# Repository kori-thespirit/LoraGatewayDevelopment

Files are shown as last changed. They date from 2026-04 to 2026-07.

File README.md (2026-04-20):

# ESP32-S3 Pin
| Pin Number | Pin Name | Function | Device |
| :--- | :--- | :--- | :--- |
| 5 | GPIO5 (ESP_TX) | HMI_RX | HMI Dwin |
| 6 | GPIO6 (ESP_RX) | HMI_TX | HMI Dwin |
| 39 | GPIO1 | LoRA_INTERRUPT | LoRA Module |
| 31 | GPIO38 | RESET | LoRA Module |
| 32 | GPIO39 | SCK | LoRA Module |
| 33 | GPIO40 | MISO | LoRA Module |
| 34 | GPIO41 | MOSI | LoRA Module |
| 35 | GPIO42 | CS | LoRA Module |
| 18 | GPIO10 | I2C_SCL | Module RTC_DS3231 |
| 19 | GPIO11 | I2C_SDA | Module RTC_DS3231 |
| 15 | GPIO3 | SIM_PWRKEY | SIMCOM |
| 7 | GPIO7 | SIM_RESET | SIMCOM |
| 23 | GPIO21 (ESP_TX) | SIM_RX | SIMCOM |
| 24 | GPIO47 (ESP_RX) | SIM_TX | SIMCOM |
| 12 | GPIO8 | CS | W5500_ETHERNET |
| 17 | GPIO9 | INTERRUPT | W5500_ETHERNET |
| 9 | GPIO16 | MOSI | W5500_ETHERNET |
| 10 | GPIO17 | MISO | W5500_ETHERNET |
| 11 | GPIO18 | SPI_CLK | W5500_ETHERNET |
| 22 | GPIO14 | SDIO_CLK | SD CARD |
| 8 | GPIO15 | SDIO_CMD | SD CARD |
| 20 | GPIO12 | SDIO_DATA0 | SD CARD |
| 21 | GPIO13 | SDIO_DATA1 | SD CARD |
| 4 | GPIO4 | SDIO_DATA2 | SD CARD |
| 38 | GPIO2 | SDIO_DATA3 | SD CARD |
| 26 | GPIO45 | SDIO_DET | SD CARD |

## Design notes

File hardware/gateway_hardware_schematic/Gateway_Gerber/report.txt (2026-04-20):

Warning: Width correction constrained.  The width correction value must be in the range of [0.000001 mm; 0.199999 mm] for the current design rules.
Plotted to 'C:\Users\ASUS\Documents\A0_LoraNode_Gateway\LoraGatewayDevelopment\hardware\Gateway_Schematic_V3\Gateway_Gerber\Gateway_Schematic_V3-F_Cu.gbr'.
Plotted to 'C:\Users\ASUS\Documents\A0_LoraNode_Gateway\LoraGatewayDevelopment\hardware\Gateway_Schematic_V3\Gateway_Gerber\Gateway_Schematic_V3-B_Cu.gbr'.
Plotted to 'C:\Users\ASUS\Documents\A0_LoraNode_Gateway\LoraGatewayDevelopment\hardware\Gateway_Schematic_V3\Gateway_Gerber\Gateway_Schematic_V3-F_Paste.gbr'.
Plotted to 'C:\Users\ASUS\Documents\A0_LoraNode_Gateway\LoraGatewayDevelopment\hardware\Gateway_Schematic_V3\Gateway_Gerber\Gateway_Schematic_V3-B_Paste.gbr'.
Plotted to 'C:\Users\ASUS\Documents\A0_LoraNode_Gateway\LoraGatewayDevelopment\hardware\Gateway_Schematic_V3\Gateway_Gerber\Gateway_Schematic_V3-F_Silkscreen.gbr'.
Plotted to 'C:\Users\ASUS\Documents\A0_LoraNode_Gateway\LoraGatewayDevelopment\hardware\Gateway_Schematic_V3\Gateway_Gerber\Gateway_Schematic_V3-B_Silkscreen.gbr'.
Plotted to 'C:\Users\ASUS\Documents\A0_LoraNode_Gateway\LoraGatewayDevelopment\hardware\Gateway_Schematic_V3\Gateway_Gerber\Gateway_Schematic_V3-F_Mask.gbr'.
Plotted to 'C:\Users\ASUS\Documents\A0_LoraNode_Gateway\LoraGatewayDevelopment\hardware\Gateway_Schematic_V3\Gateway_Gerber\Gateway_Schematic_V3-B_Mask.gbr'.
Plotted to 'C:\Users\ASUS\Documents\A0_LoraNode_Gateway\LoraGatewayDevelopment\hardware\Gateway_Schematic_V3\Gateway_Gerber\Gateway_Schematic_V3-Edge_Cuts.gbr'.
Created Gerber job file 'C:\Users\ASUS\Documents\A0_LoraNode_Gateway\LoraGatewayDevelopment\hardware\Gateway_Schematic_V3\Gateway_Gerber\Gateway_Schematic_V3-job.gbrjob'.
Info: Done.

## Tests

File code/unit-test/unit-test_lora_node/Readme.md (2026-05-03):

# Hướng dẫn bắt đầu với Unit Test LoRa Node
Folder unit_test_lora_node được thiết kế để kiểm tra khả năng gửi dữ liệu từ ESP32 qua module LoRa SX127x.
## 1. Clone Project và Truy cập folder unit_test_lora_node

### Clone toàn bộ dự án
```raw
git clone https://github.com/kori-thespirit/LoraGatewayDevelopment.git
```
### Truy cập folder unit_test_lora_node
```raw
cd LoraGatewayDevelopment/code/unit-test/unit_test_lora_gateway
```
## 2. Nạp code 
```raw
idf.py set-target esp32
idf.py -p COM? build flash monitor
```

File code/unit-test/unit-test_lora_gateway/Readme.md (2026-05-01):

# Hướng dẫn bắt đầu với Unit Test LoRa Gateway
Folder unit_test_lora_gateway được thiết kế để kiểm tra khả năng gửi dữ liệu từ ESP32 qua module LoRa SX127x.
## 1. Clone Project và Truy cập folder unit_test_lora_gateway

### Clone toàn bộ dự án
```raw
git clone https://github.com/kori-thespirit/LoraGatewayDevelopment.git
```
### Truy cập folder unit_test_lora_gateway
```raw
cd LoraGatewayDevelopment/code/unit-test/unit_test_lora_gateway
```
## 2. Nạp code 
```raw
idf.py set-target esp32s3
idf.py -p COM? build flash monitor
```

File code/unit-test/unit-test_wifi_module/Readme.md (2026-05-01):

# Unit Test: ESP32 Wi-Fi Station
## 1. Chức năng
Test chức năng kết nối WiFi tới một mạng SSID nào đó
## 2. Hướng dẫn cấu hình WiFi
Thay đổi trực tiếp tại main/unit_test_wifi.c:
```raw
#define WIFI_SSID      "IoTVision_2.4GHz"
#define WIFI_PASS      "iotvision@2022"
#define MAXIMUM_RETRY  5
```

## 3. Thao tác nạp chương trình
```raw
idf.py set-target esp32s3
idf.py -p COM? build flash monitor
```
## 4. Kết quả đạt được
```raw
I (5002) wifi:dp: 1, bi: 102400, li: 3, scale listen interval from 307200 us to 307200 us
I (5022) wifi:AP's beacon interval = 102400 us, DTIM period = 1
I (5032) wifi:<ba-add>idx:0 (ifx:0, 9a:25:4a:42:bf:2c), tid:7, ssn:2, winSize:64
I (5032) wifi:<ba-add>idx:1 (ifx:0, 9a:25:4a:42:bf:2c), tid:0, ssn:0, winSize:64
I (6022) esp_netif_handlers: sta ip: 192.168.0.51, mask: 255.255.255.0, gw: 192.168.0.1
I (6022) wifi_test: Đã nhận IP:192.168.0.51
I (6022) wifi_test: KẾT NỐI THÀNH CÔNG SSID:IoTVision_2.4GHz
```

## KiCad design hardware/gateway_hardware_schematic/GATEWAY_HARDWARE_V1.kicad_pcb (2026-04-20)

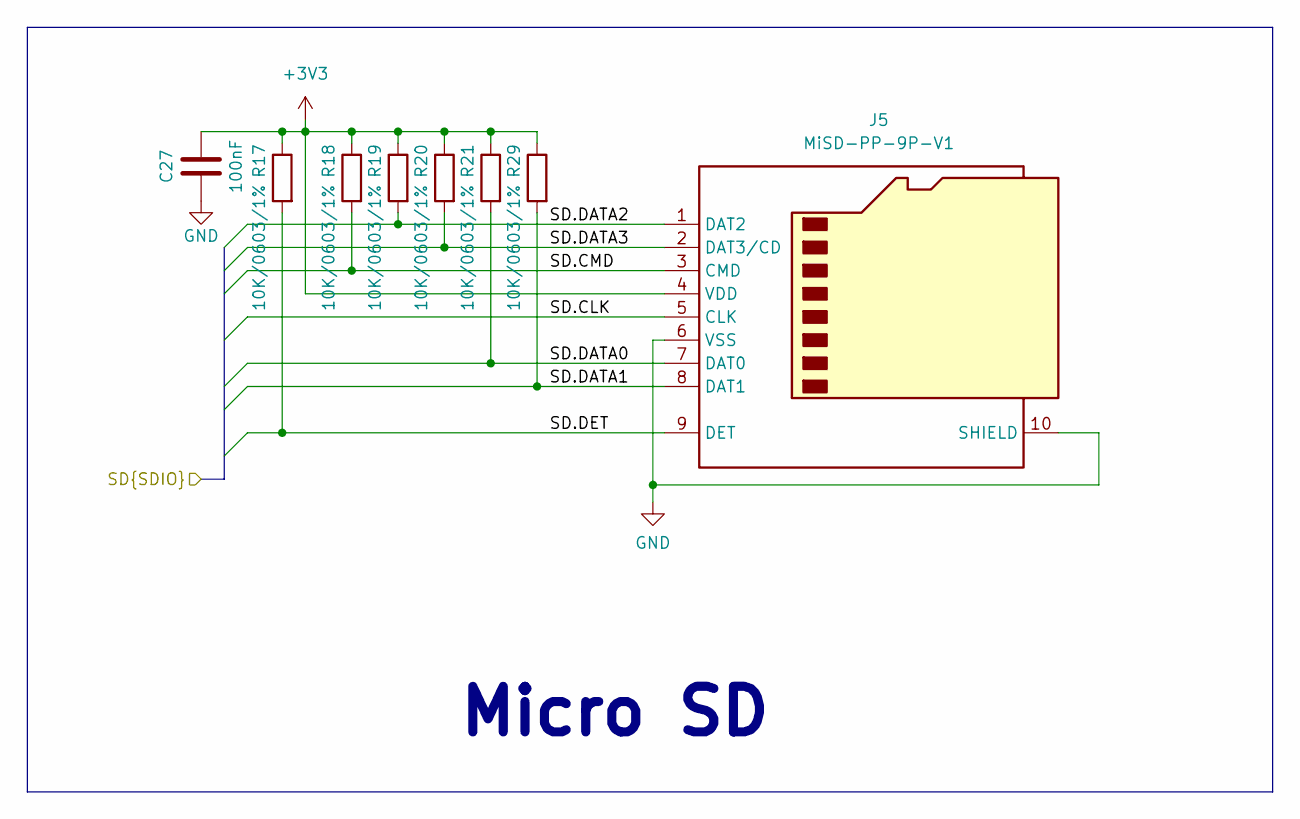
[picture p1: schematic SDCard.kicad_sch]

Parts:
C27: 100nF; C_0603
J5: MiSD-PP-9P-V1; MicroSD_Socket_9P
R17, R18, R19, R20, R21, R29: 10K/0603/1%; R_0603

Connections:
+3.3V: C27.2, J5.4 (VDD), R17.1, R18.1, R19.1, R20.1, R21.1, R29.1; also elsewhere on the board
/ESP32-S3/ESP.CLK: J5.5 (CLK); also elsewhere on the board
/ESP32-S3/ESP.CMD: J5.3 (CMD), R18.2; also elsewhere on the board
/ESP32-S3/ESP.DATA0: J5.7 (DAT0), R21.2; also elsewhere on the board
/ESP32-S3/ESP.DATA1: J5.8 (DAT1), R29.2; also elsewhere on the board
/ESP32-S3/ESP.DATA2: J5.1 (DAT2), R19.2; also elsewhere on the board
/ESP32-S3/ESP.DATA3: J5.2 (DAT3/CD), R20.2; also elsewhere on the board
/ESP32-S3/ESP.DET: J5.9 (DET), R17.2; also elsewhere on the board
GND: C27.1, J5.6 (VSS), J5.10 (SHIELD); also elsewhere on the board

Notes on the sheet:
Micro SD

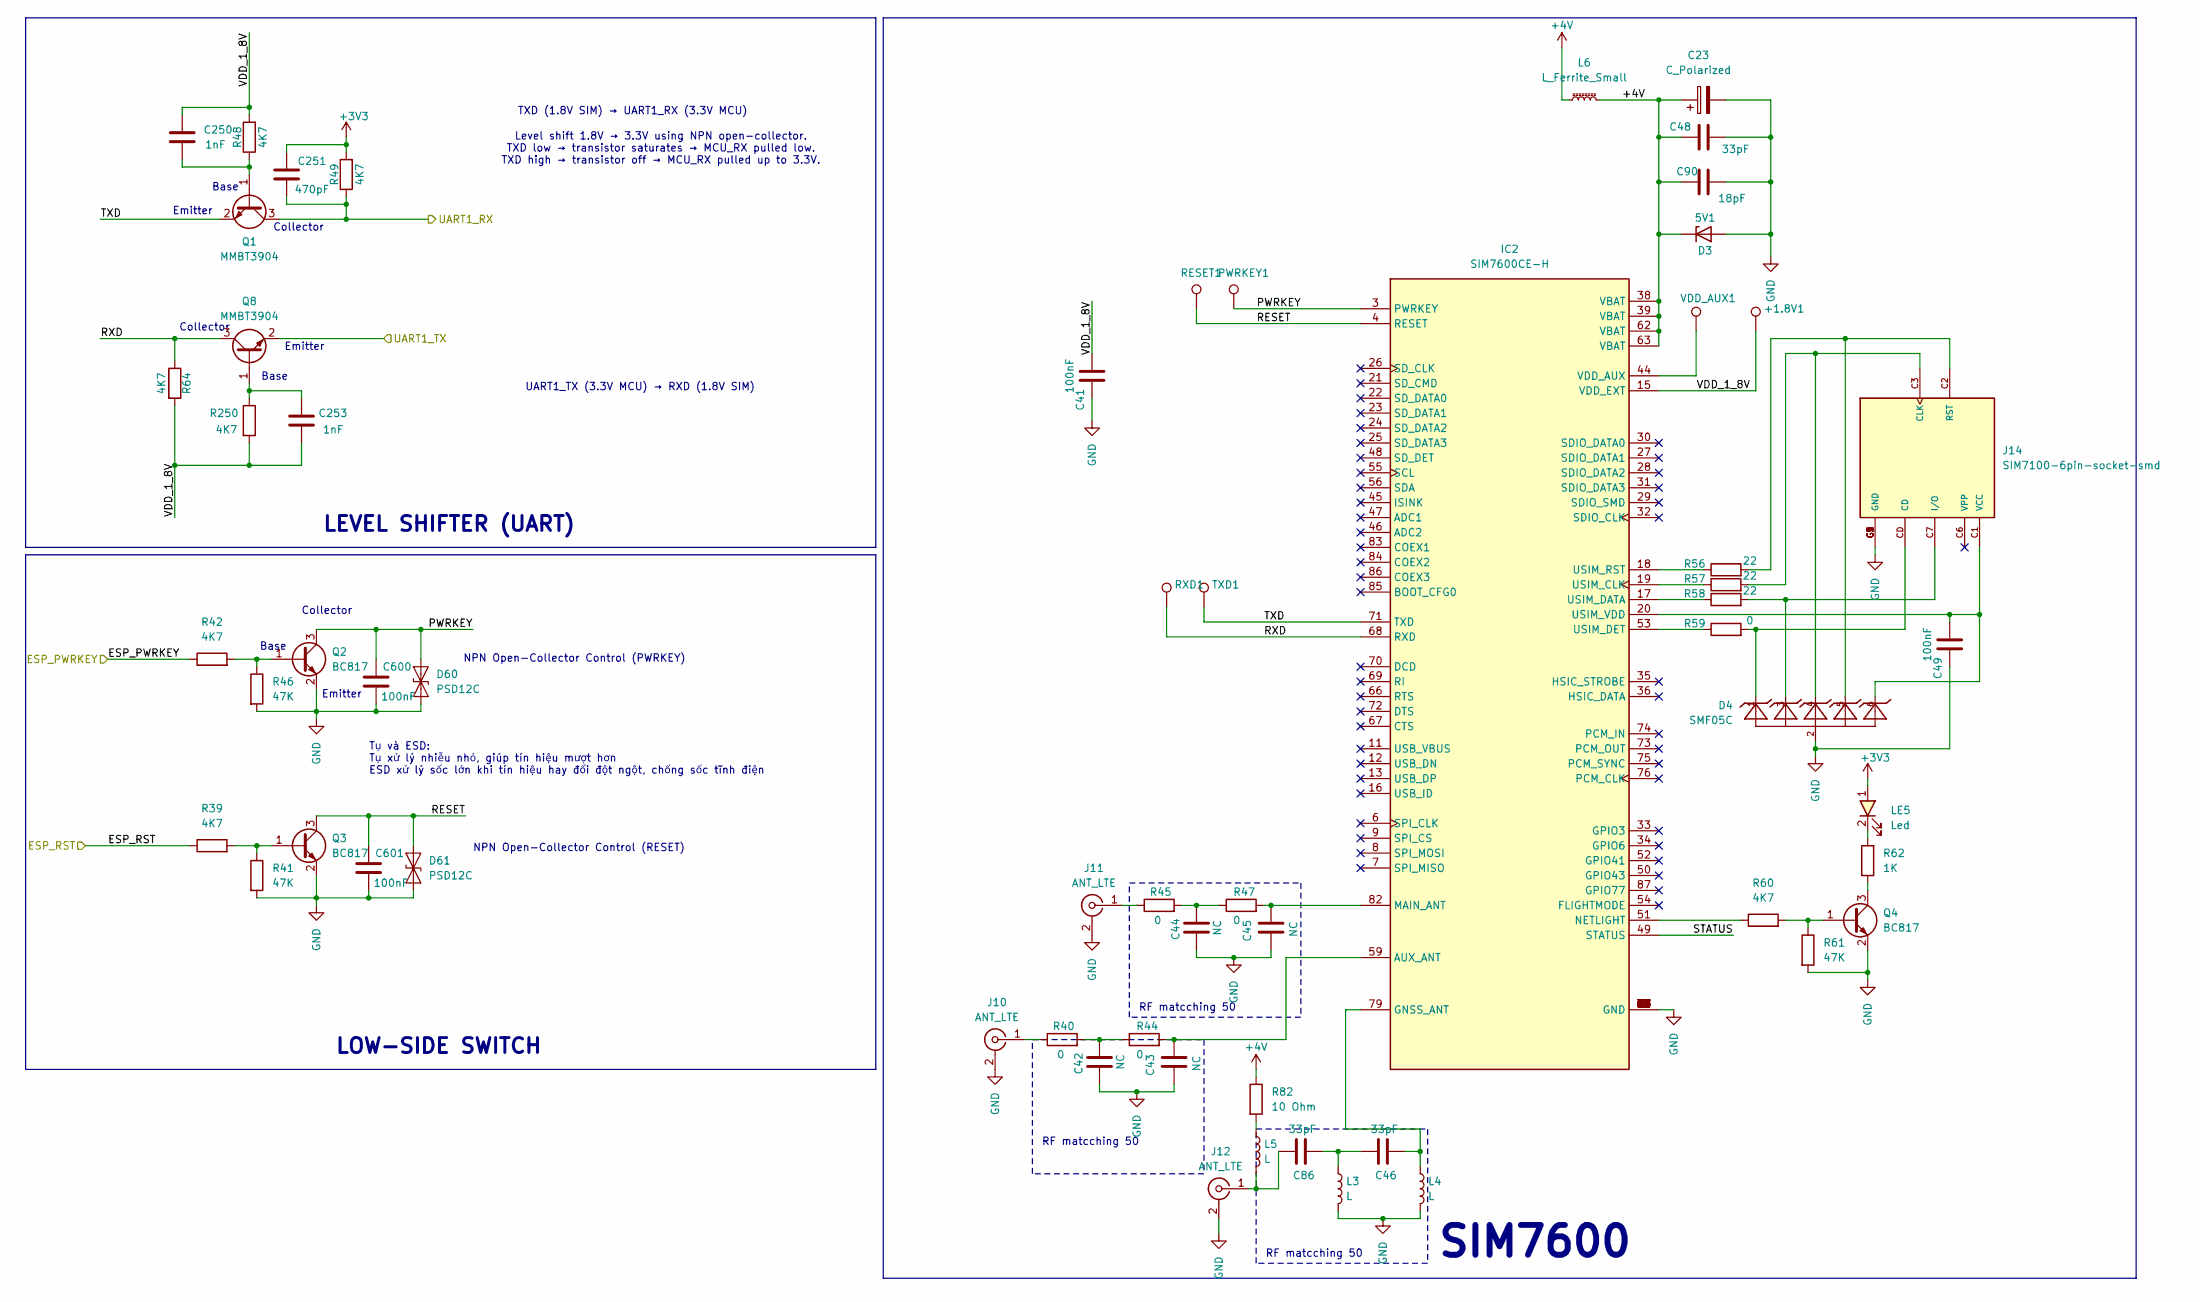
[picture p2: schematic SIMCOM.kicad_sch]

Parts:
+1.8V1: TestPoint_throughtHole_D1.0mm
C23: C_Polarized; CP_Elec_6.3x7.7
C41, C49: 100nF; C_0603_1608Metric
C42, C43, C44, C45: NC; C_0603_1608Metric
C46, C48, C86: 33pF; C_0603_1608Metric
C90: 18pF; C_0603_1608Metric
C250, C253: 1nF; C_0603
C251: 470pF; C_0603
C600, C601: 100nF; C_0603
D3: 5V1; D_SOD-123
D4: SMF05C; SC70-6
D60, D61: PSD12C; D_SOD-323
IC2: SIM7600CE-H; SIM7600
J10, J11, J12: ANT_LTE; Conn_IPEX_ANT; MPN BWU.FL-IPEX1; LCSC C5137195
J14: SIM7100-6pin-socket-smd; CUI_NSIM-1-A; PARTREV C2
L3, L4, L5: L; L_0603_1608Metric
L6: L_Ferrite_Small; L_0805
LE5: Led; LED_0603_1608Metric
PWRKEY1: TestPoint_throughtHole_D1.0mm
Q1, Q8: MMBT3904; SOT-23
Q2, Q3, Q4: BC817; SOT-23
R39, R42, R48, R49, R60, R64: 4K7; R_0603_1608Metric
R40, R44, R45, R47, R59: 0; R_0603_1608Metric
R41, R46, R61: 47K; R_0603_1608Metric
R56, R57, R58: 22; R_0603_1608Metric
R62: 1K; R_0603_1608Metric
R82: 10 Ohm; R_0603_1608Metric
R250: 4K7; R_0603
RESET1: TestPoint_throughtHole_D1.0mm
RXD1: TestPoint_throughtHole_D1.0mm
TXD1: TestPoint_throughtHole_D1.0mm
VDD_AUX1: TestPoint_throughtHole_D1.0mm

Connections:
+3.3V: C251.1, LE5.1, R49.2; also elsewhere on the board
+4V: C23.1, C48.1, C90.1, D3.1 (K), IC2.38 (VBAT), IC2.39 (VBAT), IC2.62 (VBAT), IC2.63 (VBAT), L6.1, L6.2, R82.1; also elsewhere on the board
/ESP32-S3/UART1_RX: C251.2, Q1.3 (C), R49.1; also elsewhere on the board
/ESP32-S3/UART1_TX: Q8.2 (E); also elsewhere on the board
/SIMCOM/ESP_PWRKEY: R42.1; also elsewhere on the board
/SIMCOM/ESP_RST: R39.1; also elsewhere on the board
/SIMCOM/PWRKEY: C600.1, D60.2 (A2), IC2.3 (PWRKEY), PWRKEY1.1, Q2.3 (C)
/SIMCOM/RESET: C601.1, D61.2 (A2), IC2.4 (RESET), Q3.3 (C), RESET1.1
/SIMCOM/RXD: IC2.68 (RXD), Q8.3 (C), R64.1, RXD1.1
/SIMCOM/STATUS: IC2.49 (STATUS)
/SIMCOM/TXD: IC2.71 (TXD), Q1.2 (E), TXD1.1
/SIMCOM/VDD_1_8V: +1.8V1.1, C41.1, C250.1, C253.2, IC2.15 (VDD_EXT), R48.2, R64.2, R250.2
GND: C23.2, C41.2, C42.1, C43.1, C44.1, C45.1, C48.2, C49.2, C90.2, C600.2, C601.2, D3.2 (A), D4.2, D60.1 (A1), D61.1 (A1), IC2.1 (GND), IC2.2 (GND), IC2.5 (GND), IC2.10 (GND), IC2.14 (GND), IC2.37 (GND), IC2.40 (GND), IC2.41 (GND), IC2.43 (GND), IC2.57 (GND), IC2.58 (GND), IC2.60 (GND), IC2.61 (GND), IC2.64 (GND), IC2.65 (GND), IC2.77 (GND), IC2.78 (GND), IC2.80 (GND), IC2.81 (GND), J10.2 (Ext), J11.2 (Ext), J12.2 (Ext), J14.C5 (GND), J14.G1 (GND), J14.G2 (GND), J14.G3 (GND), J14.G4 (GND), L3.2, L4.2, Q2.2 (E), Q3.2 (E), Q4.2 (E), R41.2, R46.2, R61.2; also elsewhere on the board
unnamed: C42.2, R40.2, R44.1
unnamed: C44.2, R45.2, R47.1
unnamed: C46.2, C86.1, L3.1
unnamed: D4.1, J14.CD, R59.2
unnamed: C43.2, IC2.59 (AUX_ANT), R44.2
unnamed: C46.1, IC2.79 (GNSS_ANT), L4.1
unnamed: C45.2, IC2.82 (MAIN_ANT), R47.2
unnamed: IC2.51 (NETLIGHT), R60.1
unnamed: IC2.19 (USIM_CLK), R57.1
unnamed: IC2.17 (USIM_DATA), R58.1
unnamed: IC2.53 (USIM_DET), R59.1
unnamed: IC2.18 (USIM_RST), R56.1
unnamed: C49.1, D4.6, IC2.20 (USIM_VDD), J14.C1 (VCC)
unnamed: IC2.44 (VDD_AUX), VDD_AUX1.1
unnamed: J10.1 (In), R40.1
unnamed: J11.1 (In), R45.1
unnamed: C86.2, J12.1 (In), L5.2
unnamed: D4.4, J14.C3 (CLK), R57.2
unnamed: D4.3, J14.C7 (I/O), R58.2
unnamed: D4.5, J14.C2 (RST), R56.2
unnamed: L5.1, R82.2
unnamed: LE5.2, R62.2
unnamed: C250.2, Q1.1 (B), R48.1
unnamed: Q2.1 (B), R42.2, R46.1
unnamed: Q3.1 (B), R39.2, R41.1
unnamed: Q4.1 (B), R60.2, R61.1
unnamed: Q4.3 (C), R62.1
unnamed: C253.1, Q8.1 (B), R250.1

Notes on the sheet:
NPN Open-Collector Control (RESET)
Emitter
Collector
UART1_TX (3.3V MCU) → RXD (1.8V SIM)
SIM7600
RF matcching 50
Collector
Emitter
Base
LEVEL SHIFTER (UART)
Tụ và ESD: Tụ xử lý nhiễu nhỏ, giúp tín hiệu mượt hơn ESD xử lý sốc lớn khi tín hiệu hay đổi đột ngột, chống sốc tĩnh điện
Level shift 1.8V → 3.3V using NPN open-collector. TXD low → transistor saturates → MCU_RX pulled low. TXD high → transistor off → MCU_RX pulled up to 3.3V.
TXD (1.8V SIM) → UART1_RX (3.3V MCU)
NPN Open-Collector Control (PWRKEY)
LOW-SIDE SWITCH

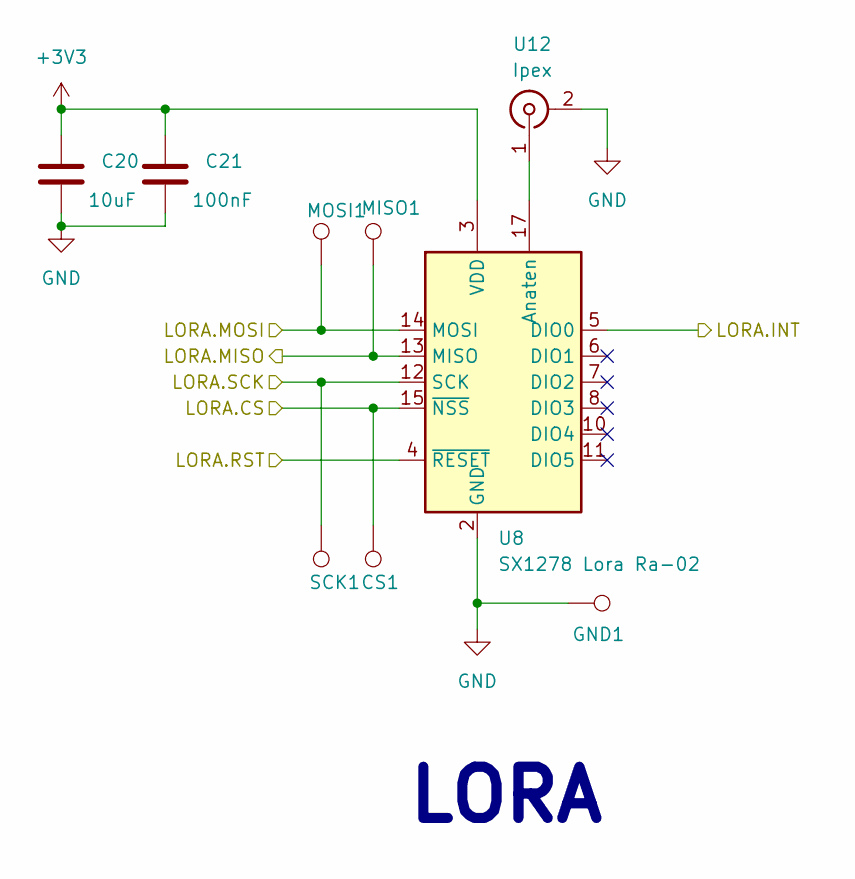
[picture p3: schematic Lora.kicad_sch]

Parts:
C20: 10uF; C_0603
C21: 100nF; C_0603
CS1: TestPoint; TestPoint_throughtHole_D1.0mm
GND1: TestPoint; TestPoint_throughtHole_D1.0mm
MISO1: TestPoint; TestPoint_throughtHole_D1.0mm
MOSI1: TestPoint; TestPoint_throughtHole_D1.0mm
SCK1: TestPoint; TestPoint_throughtHole_D1.0mm
U8: SX1278 Lora Ra-02; MODULE_RA-02_LORA
U12: Ipex; Conn_IPEX_ANT

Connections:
+3.3V: C20.1, C21.1, U8.3 (VDD); also elsewhere on the board
/ESP32-S3/LORA.CS: CS1.1, U8.15 (~NSS); also elsewhere on the board
/ESP32-S3/LORA.INT: U8.5 (DIO0); also elsewhere on the board
/ESP32-S3/LORA.MISO: MISO1.1, U8.13 (MISO); also elsewhere on the board
/ESP32-S3/LORA.MOSI: MOSI1.1, U8.14 (MOSI); also elsewhere on the board
/ESP32-S3/LORA.RST: U8.4 (~RESET); also elsewhere on the board
/ESP32-S3/LORA.SCK: SCK1.1, U8.12 (SCK); also elsewhere on the board
GND: C20.2, C21.2, GND1.1, U8.1 (GND), U8.2 (GND), U8.9 (GND), U8.16 (GND), U12.2; also elsewhere on the board
unnamed: U8.17 (Anaten), U12.1

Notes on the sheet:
LORA

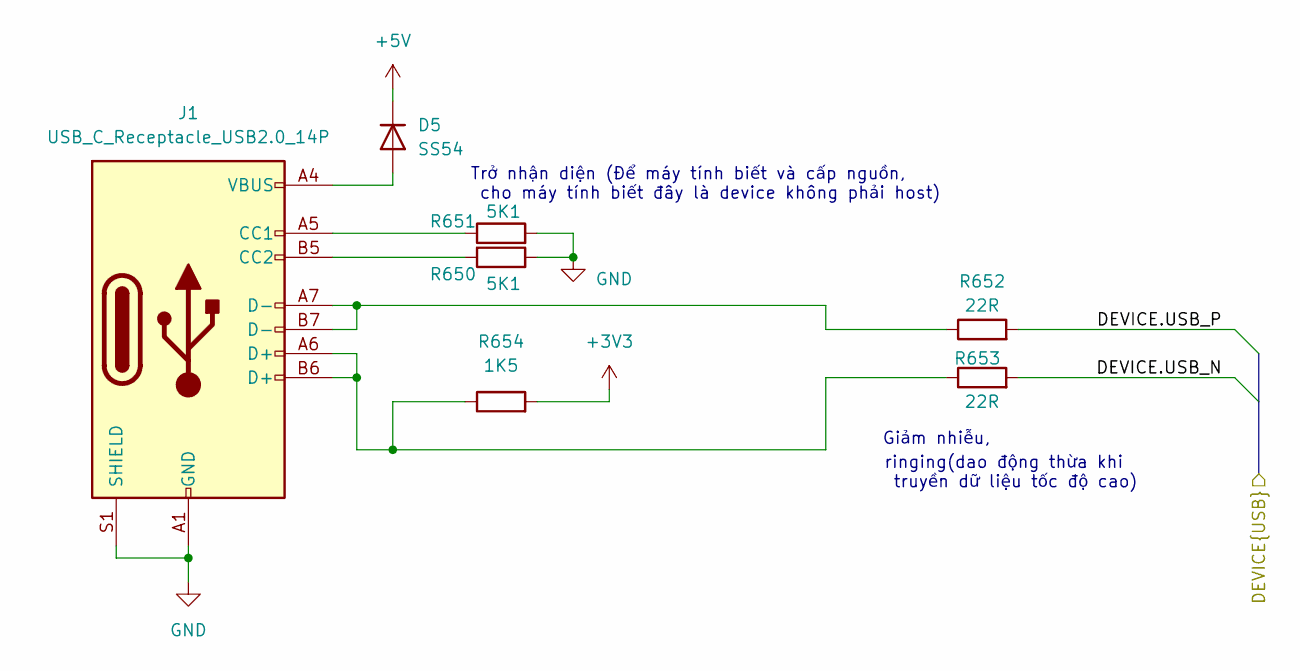
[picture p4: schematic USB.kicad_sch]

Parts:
D5: SS54; D_SMA
J1: USB_C_Receptacle_USB2.0_14P; USB_C_Receptacle_GCT_USB4105-xx-A_16P_TopMnt_Horizontal
R650, R651: 5K1; R_0805_2012Metric_Pad1.20x1.40mm_HandSolder
R652, R653: 22R; R_0603
R654: 1K5; R_0603

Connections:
+3.3V: R654.2; also elsewhere on the board
+5V: D5.1 (K); also elsewhere on the board
/ESP32-S3/ESP.USB_N: R653.2; also elsewhere on the board
/ESP32-S3/ESP.USB_P: R652.2; also elsewhere on the board
GND: J1.A1 (GND), J1.A12 (GND), J1.B1 (GND), J1.B12 (GND), J1.S1 (SHIELD), R650.2, R651.2; also elsewhere on the board
unnamed: D5.2 (A), J1.A4 (VBUS), J1.A9 (VBUS), J1.B4 (VBUS), J1.B9 (VBUS)
unnamed: J1.A5 (CC1), R651.1
unnamed: J1.B5 (CC2), R650.1
unnamed: J1.A6 (D+), J1.B6 (D+), R653.1, R654.1
unnamed: J1.A7 (D-), J1.B7 (D-), R652.1

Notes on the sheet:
Giảm nhiễu,
Trở nhận diện (Để máy tính biết và cấp nguồn, cho máy tính biết đây là device không phải host)
ringing(dao động thừa khi truyền dữ liệu tốc độ cao)

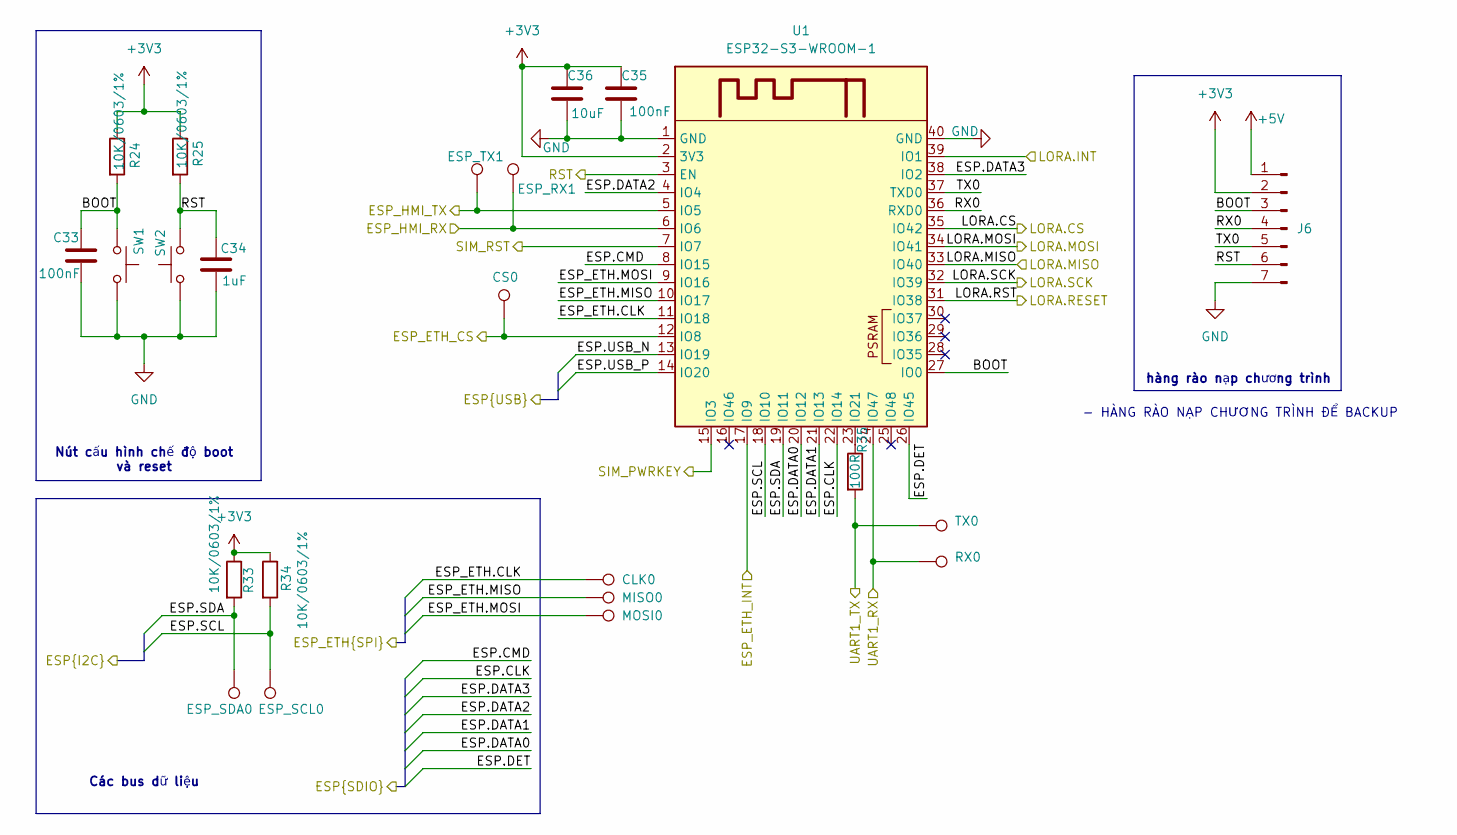
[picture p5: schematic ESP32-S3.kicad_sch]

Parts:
C33, C35: 100nF; C_0603
C34: 1uF; C_0603
C36: 10uF; C_0603
CLK0: TestPoint_throughtHole_D1.0mm
CS0: TestPoint_throughtHole_D1.0mm
ESP_RX1: TestPoint; TestPoint_throughtHole_D1.0mm
ESP_SCL0: TestPoint; TestPoint_throughtHole_D1.0mm
ESP_SDA0: TestPoint; TestPoint_throughtHole_D1.0mm
ESP_TX1: TestPoint; TestPoint_throughtHole_D1.0mm
J6: Conn_01x07_Pin; PinHeader_1x07_P2.54mm_Vertical
MISO0: TestPoint_throughtHole_D1.0mm
MOSI0: TestPoint_throughtHole_D1.0mm
R24, R25, R33, R34: 10K/0603/1%; R_0603
R35: 100R; R_0603
RX0: TestPoint_throughtHole_D1.0mm
SW1, SW2: SW_Push; SW_SPST_PTS810
TX0: TestPoint_throughtHole_D1.0mm
U1: ESP32-S3-WROOM-1

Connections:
+3.3V: C35.1, C36.1, J6.2, R24.1, R25.1, R33.1, R34.1, U1.2 (3V3); also elsewhere on the board
+5V: J6.1; also elsewhere on the board
/ESP32-S3/BOOT: C33.1, J6.3, R24.2, SW1.2, U1.27 (IO0)
/ESP32-S3/ESP.CLK: U1.22 (IO14); also elsewhere on the board
/ESP32-S3/ESP.CMD: U1.8 (IO15); also elsewhere on the board
/ESP32-S3/ESP.DATA0: U1.20 (IO12); also elsewhere on the board
/ESP32-S3/ESP.DATA1: U1.21 (IO13); also elsewhere on the board
/ESP32-S3/ESP.DATA2: U1.4 (IO4); also elsewhere on the board
/ESP32-S3/ESP.DATA3: U1.38 (IO2); also elsewhere on the board
/ESP32-S3/ESP.DET: U1.26 (IO45); also elsewhere on the board
/ESP32-S3/ESP.SCL: ESP_SCL0.1, R34.2, U1.18 (IO10); also elsewhere on the board
/ESP32-S3/ESP.SDA: ESP_SDA0.1, R33.2, U1.19 (IO11); also elsewhere on the board
/ESP32-S3/ESP.USB_N: U1.13 (IO19); also elsewhere on the board
/ESP32-S3/ESP.USB_P: U1.14 (IO20); also elsewhere on the board
/ESP32-S3/ESP_ETH.CLK: CLK0.1, U1.11 (IO18); also elsewhere on the board
/ESP32-S3/ESP_ETH.MISO: MISO0.1, U1.10 (IO17); also elsewhere on the board
/ESP32-S3/ESP_ETH.MOSI: MOSI0.1, U1.9 (IO16); also elsewhere on the board
/ESP32-S3/ESP_ETH_CS: CS0.1, U1.12 (IO8); also elsewhere on the board
/ESP32-S3/ESP_ETH_INT: U1.17 (IO9); also elsewhere on the board
/ESP32-S3/ESP_HMI_RX: ESP_RX1.1, U1.6 (IO6); also elsewhere on the board
/ESP32-S3/ESP_HMI_TX: ESP_TX1.1, U1.5 (IO5); also elsewhere on the board
/ESP32-S3/LORA.CS: U1.35 (IO42); also elsewhere on the board
/ESP32-S3/LORA.INT: U1.39 (IO1); also elsewhere on the board
/ESP32-S3/LORA.MISO: U1.33 (IO40); also elsewhere on the board
/ESP32-S3/LORA.MOSI: U1.34 (IO41); also elsewhere on the board
/ESP32-S3/LORA.RST: U1.31 (IO38); also elsewhere on the board
/ESP32-S3/LORA.SCK: U1.32 (IO39); also elsewhere on the board
/ESP32-S3/RST: C34.1, J6.6, R25.2, SW2.2, U1.3 (EN)
/ESP32-S3/RX0: J6.4, U1.36 (RXD0)
/ESP32-S3/TX0: J6.5, U1.37 (TXD0)
/ESP32-S3/UART1_RX: RX0.1, U1.24 (IO47); also elsewhere on the board
/ESP32-S3/UART1_TX: R35.2, TX0.1; also elsewhere on the board
/SIMCOM/ESP_PWRKEY: U1.15 (IO3); also elsewhere on the board
/SIMCOM/ESP_RST: U1.7 (IO7); also elsewhere on the board
GND: C33.2, C34.2, C35.2, C36.2, J6.7, SW1.1, SW2.1, U1.1 (GND), U1.40 (GND), U1.41 (GND); also elsewhere on the board
unnamed: R35.1, U1.23 (IO21)

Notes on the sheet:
Các bus dữ liệu
hàng rào nạp chương trình
Nút cấu hình chế độ boot và reset
- HÀNG RÀO NẠP CHƯƠNG TRÌNH ĐỂ BACKUP

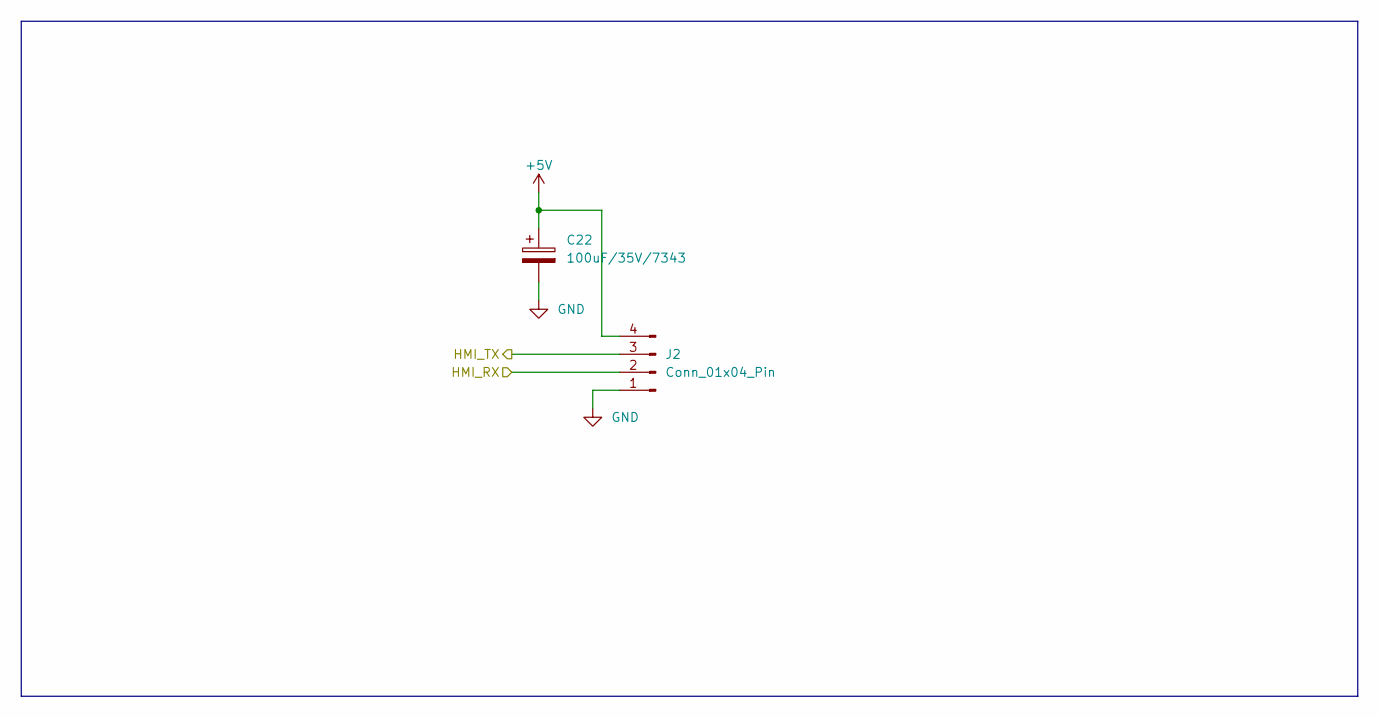
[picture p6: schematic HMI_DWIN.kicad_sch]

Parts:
C22: 100uF/35V/7343; CP_EIA-7132-28_AVX-C_Pad2.72x3.50mm_HandSolder
J2: Conn_01x04_Pin; Conn_XH-P2.54mm-4P

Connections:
+5V: C22.1, J2.4; also elsewhere on the board
/ESP32-S3/ESP_HMI_RX: J2.3; also elsewhere on the board
/ESP32-S3/ESP_HMI_TX: J2.2; also elsewhere on the board
GND: C22.2, J2.1; also elsewhere on the board

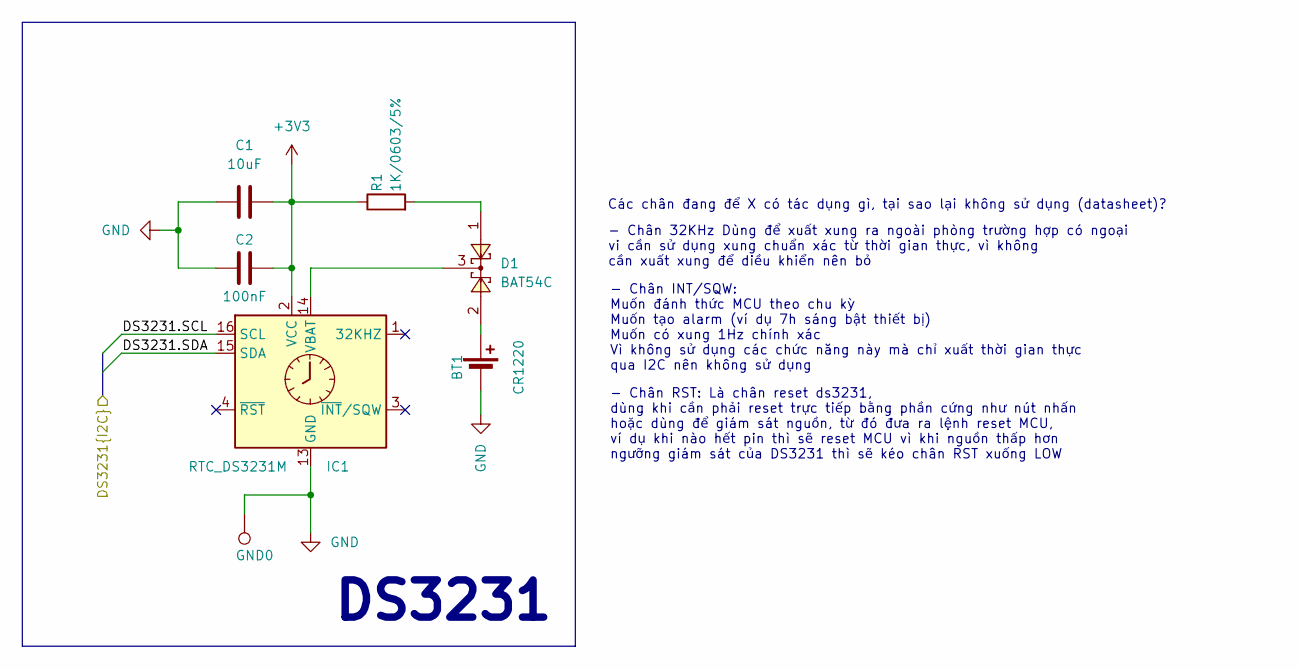
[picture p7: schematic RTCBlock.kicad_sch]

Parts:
BT1: CR1220; BatteryHolder_CR1220
C1: 10uF; C_0603
C2: 100nF; C_0603
D1: BAT54C; SOT23-3
GND0: TestPoint; TestPoint_throughtHole_D1.0mm
IC1: RTC_DS3231M; SOIC-16W_7.5x10.3mm_P1.27mm
R1: 1K/0603/5%; R_0603

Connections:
+3.3V: C1.2, C2.2, IC1.2 (VCC), R1.1; also elsewhere on the board
/ESP32-S3/ESP.SCL: IC1.16 (SCL); also elsewhere on the board
/ESP32-S3/ESP.SDA: IC1.15 (SDA); also elsewhere on the board
GND: BT1.2 (-), C1.1, C2.1, GND0.1, IC1.5 (GND), IC1.6 (GND), IC1.7 (GND), IC1.8 (GND), IC1.9 (GND), IC1.10 (GND), IC1.11 (GND), IC1.12 (GND), IC1.13 (GND); also elsewhere on the board
unnamed: BT1.1 (+), D1.2
unnamed: D1.1, R1.2
unnamed: D1.3, IC1.14 (VBAT)

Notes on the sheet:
- Chân 32KHz Dùng để xuất xung ra ngoài phòng trường hợp có ngoại vi cần sử dụng xung chuẩn xác từ thời gian thực, vì không cần xuất xung để diều khiển nên bỏ
- Chân RST: Là chân reset ds3231, dùng khi cần phải reset trực tiếp bằng phần cứng như nút nhấn hoặc dùng để giám sát nguồn, từ đó đưa ra lệnh reset MCU, ví dụ khi nào hết pin thì sẽ reset MCU vì khi nguồn thấp hơn ngưỡng giám sát của DS3231 thì sẽ kéo chân RST xuống LOW
DS3231
Các chân đang để X có tác dụng gì, tại sao lại không sử dụng (datasheet)?
- Chân INT/SQW: Muốn đánh thức MCU theo chu kỳ Muốn tạo alarm (ví dụ 7h sáng bật thiết bị) Muốn có xung 1Hz chính xác Vì không sử dụng các chức năng này mà chỉ xuất thời gian thực qua I2C nên không sử dụng

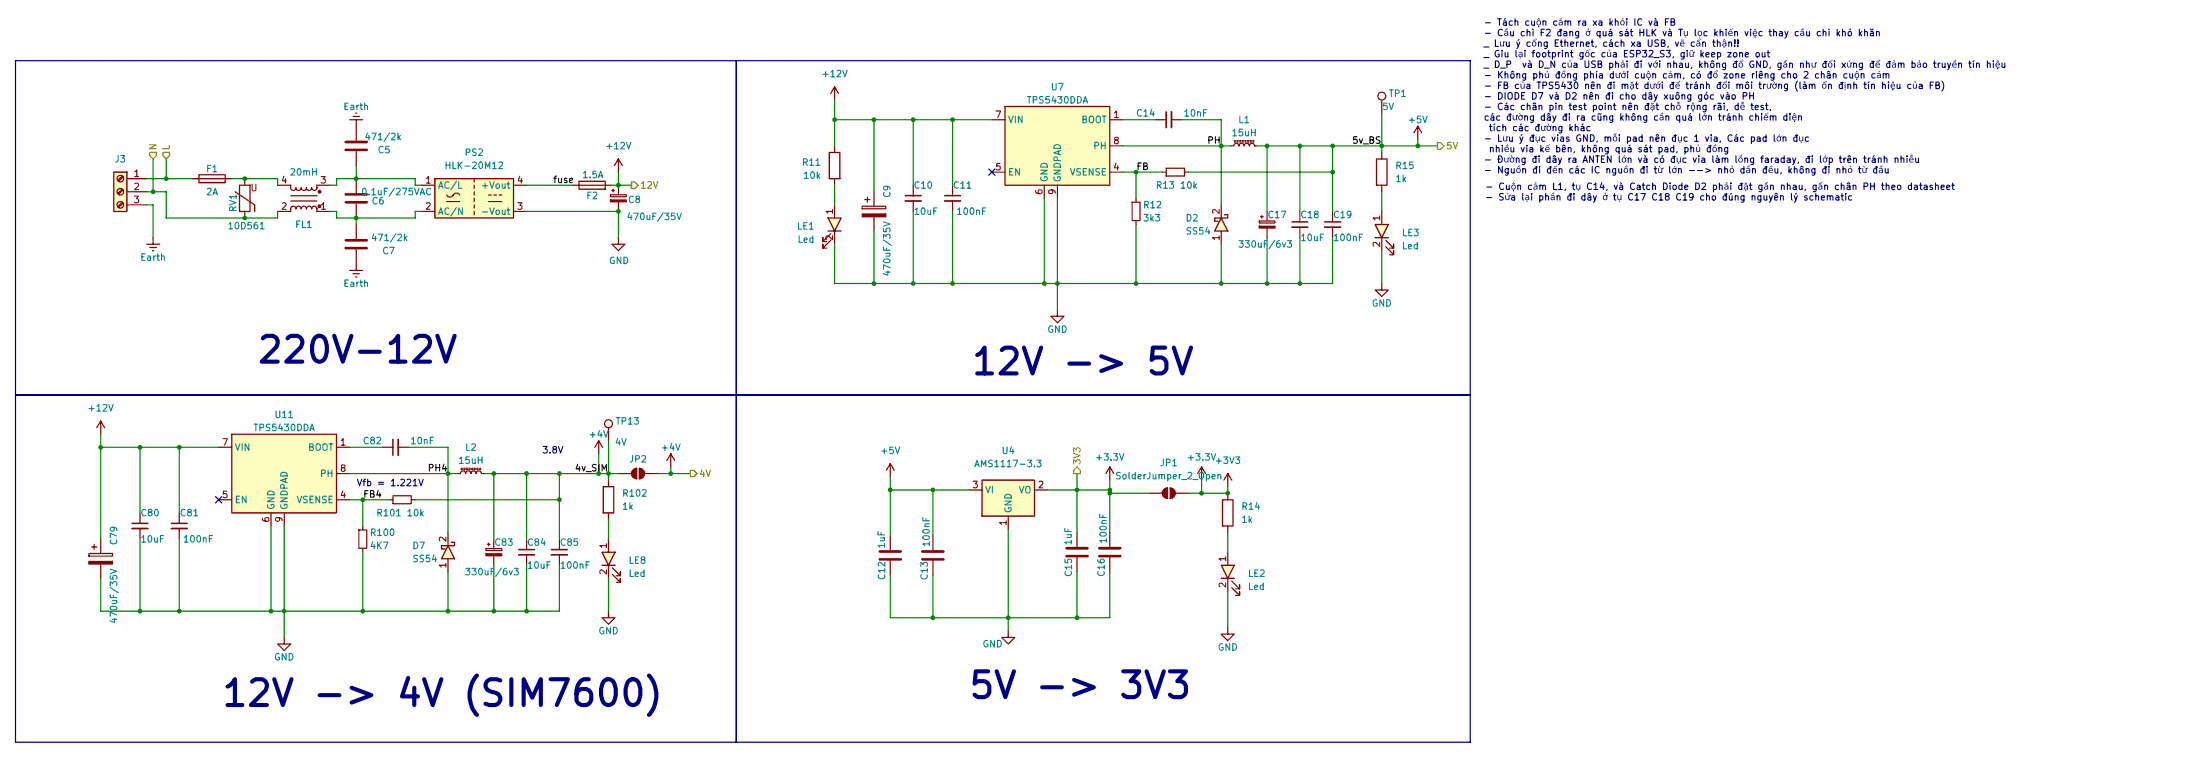
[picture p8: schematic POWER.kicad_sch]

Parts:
C5, C7: 471/2k; C_Disc_D4.3mm_W1.9mm_P5.00mm
C6: 0.1uF/275VAC; C_Rect_L16.5mm_W5.0mm_P15.00mm_MKT
C8, C9, C79: 470uF/35V; CP_Elec_10x10.5
C10, C18: 10uF; C_0805
C11, C19: 100nF; C_0805
C12, C15: 1uF; C_0603
C13, C16: 100nF; C_0603
C14: 10nF; C_0603
C17, C83: 330uF/6v3; CP_Elec_6.3x7.7
C80, C84: 10uF; C_0805_2012Metric
C81, C85: 100nF; C_0805_2012Metric
C82: 10nF; C_0603_1608Metric
D2, D7: SS54; D_SMA
F1: 2A; Fuse_HolderGlass5x20mm
F2: 1.5A; Fuse_1812_4532Metric
FL1: 20mH; ACFilterChokeUU9.8
J3: Screw_Terminal_01x03; TerminalBlock_Screw_HB9500_3pin_P9.5mm
JP1, JP2: SolderJumper_2_Open; SolderJumper-2_P1.3mm_Open_RoundedPad1.0x1.5mm
L1, L2: 15uH; L_Bourns_SRR1208_12.7x12.7mm
LE1, LE2, LE3: Led; LED_0603
LE8: Led; LED_0603_1608Metric
PS2: HLK-20M12; ACDC_HLK-20MXX
R11, R13: 10k; R_0603
R12: 3k3; R_0603
R14, R15: 1k; R_0603
R100: 4K7; R_0603_1608Metric
R101: 10k; R_0603_1608Metric
R102: 1k; R_0603_1608Metric
RV1: 10D561; RV_Disc_D12mm_W5.8mm_P7.5mm
TP1: 5V; TestPoint_throughtHole_D1.0mm
TP13: 4V; TestPoint_throughtHole_D1.0mm
U4: AMS1117-3.3; SOT-223-3_TabPin2
U7, U11: TPS5430DDA; TI_SO-PowerPAD-8_ThermalVias

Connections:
+3.3V: C15.2, C16.2, JP1.1 (A), JP1.2 (B), R14.1, U4.2 (VO); also elsewhere on the board
+4V: C83.1, C84.1, C85.1, JP2.1 (A), JP2.2 (B), L2.2, R101.2, R102.1, TP13.1; also elsewhere on the board
+5V: C12.2, C13.2, C17.1, C18.1, C19.1, L1.2, R13.2, R15.1, TP1.1, U4.3 (VI); also elsewhere on the board
+12V: C8.1, C9.1, C10.1, C11.1, C79.1, C80.1, C81.1, F2.2, R11.1, U7.7 (VIN), U11.7 (VIN)
/Khối nguồn/FB: R12.1, R13.1, U7.4 (VSENSE)
/Khối nguồn/FB4: R100.1, R101.1, U11.4 (VSENSE)
/Khối nguồn/L: F1.1, J3.1
/Khối nguồn/N: FL1.2, J3.2, RV1.1
/Khối nguồn/PH: C14.2, D2.2, L1.1, U7.8 (PH)
/Khối nguồn/PH4: C82.2, D7.2, L2.1, U11.8 (PH)
/Khối nguồn/fuse: F2.1, PS2.4 (+Vout)
Earth: C5.2, C7.1, J3.3
GND: C8.2, C9.2, C10.2, C11.2, C12.1, C13.1, C15.1, C16.1, C17.2, C18.2, C19.2, C79.2, C80.2, C81.2, C83.2, C84.2, C85.2, D2.1, D7.1, LE1.2, LE2.2, LE3.2, LE8.2, PS2.3 (-Vout), R12.2, R100.2, U4.1 (GND), U7.6 (GND), U7.9 (GNDPAD), U11.6 (GND), U11.9 (GNDPAD); also elsewhere on the board
unnamed: F1.2, FL1.4, RV1.2
unnamed: LE1.1, R11.2
unnamed: LE2.1, R14.2
unnamed: LE3.1, R15.2
unnamed: LE8.1, R102.2
unnamed: C5.1, C6.1, FL1.3, PS2.1 (AC/L)
unnamed: C6.2, C7.2, FL1.1, PS2.2 (AC/N)
unnamed: C14.1, U7.1 (BOOT)
unnamed: C82.1, U11.1 (BOOT)

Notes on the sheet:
12V -> 5V
12V -> 4V (SIM7600)
- Cuộn cảm L1, tụ C14, và Catch Diode D2 phải đặt gần nhau, gần chân PH theo datasheet - Sửa lại phần đi dây ở tụ C17 C18 C19 cho đúng nguyên lý schematic
220V-12V
3.8V
5V -> 3V3
- Tách cuộn cảm ra xa khỏi IC và FB - Cầu chì F2 đang ở quá sát HLK và Tụ lọc khiến việc thay cầu chì khó khăn _ Lưu ý cổng Ethernet, cách xa USB, vẽ cẩn thận!! _ Giu lại footprint gốc của ESP32_S3, giữ keep zone out _ D_P và D_N của USB phải đi với nhau, không đổ GND, gần như đối xứng để đảm bảo t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
Vfb = 1.221V

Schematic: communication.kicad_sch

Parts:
C55, C56: 18pF; C_0603
C57: 1uF; C_0603
C58, C69, C70, C71, C72, C73: 100nF; C_0603
C59, C63: 10nF; C_0603
C61: 4.7uF; C_0603
C65: 22nF; C_0603
C66: 10uF; C_0603
C67, C68: 6.8nF; C_0603
C74: 4.7nF; C_0603
FB1: FerriteBead_Small; L_0805
J17: HR911105A; HANRUN_RJ45LED_HR911105A
R63, R65, R69, R70, R84, R85, R86, R87: 33R; R_0603
R66, R67, R68, R71, R72, R74, R75, R76, R78, R79, R80: 10K; R_0603
R73: 1M; R_0603
R88: 12K4/1%; R_0603
R89, R90: 82R; R_0603
R92, R93: 49R9; R_0603
R95: 10R; R_0603
R96, R97: 330; R_0603
U9: W5500; LQFP-48_7x7mm_P0.5mm
Y2: 25MHz; Crystal_SMD_3225-4Pin_3.2x2.5mm

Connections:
+3.3V: C57.1, C58.1, C66.1, FB1.2, J17.9, J17.12, R66.1, R67.1, R68.1, R71.1, R72.1, U9.28 (VDD); also elsewhere on the board
/ESP32-S3/ESP_ETH.CLK: R70.1; also elsewhere on the board
/ESP32-S3/ESP_ETH.MISO: R63.1; also elsewhere on the board
/ESP32-S3/ESP_ETH.MOSI: R65.1; also elsewhere on the board
/ESP32-S3/ESP_ETH_CS: R69.1; also elsewhere on the board
/ESP32-S3/ESP_ETH_INT: R72.2, U9.36 (~INT); also elsewhere on the board
/Ethernet/ETH_RST: R71.2, U9.37 (~RST)
/Ethernet/ETH_VDDA: C69.1, C70.1, C71.1, C72.1, C73.1, FB1.1, R92.1, R93.1, R95.1, U9.4 (AVDD), U9.8 (AVDD), U9.11 (AVDD), U9.15 (AVDD), U9.17 (AVDD), U9.21 (AVDD)
GND: C55.1, C56.1, C57.2, C58.2, C59.1, C61.1, C63.1, C65.1, C66.2, C69.2, C70.2, C71.2, C72.2, C73.2, C74.2, J17.8, R74.1, R75.1, R76.1, R78.1, R79.1, R80.1, R88.2, U9.3 (AGND), U9.9 (AGND), U9.14 (AGND), U9.16 (AGND), U9.19 (AGND), U9.29 (GND), U9.48 (AGND), Y2.2, Y2.4; also elsewhere on the board
unnamed: C63.2, J17.5, R89.2, R90.2
unnamed: C65.2, J17.4, R95.2
unnamed: C67.1, R84.2, R89.1
unnamed: C67.2, J17.6
unnamed: C68.1, R85.2, R90.1
unnamed: C68.2, J17.3
unnamed: J17.1, R87.2, R92.2
unnamed: J17.2, R86.2, R93.2
unnamed: J17.10, R96.2
unnamed: J17.11, R97.2
unnamed: C74.1, J17.SH (SHIELD)
unnamed: R74.2, U9.38 (RSVD)
unnamed: R75.2, U9.39 (RSVD)
unnamed: R76.2, U9.40 (RSVD)
unnamed: R78.2, U9.41 (RSVD)
unnamed: R79.2, U9.42 (RSVD)
unnamed: R80.2, U9.23 (RSVD)
unnamed: C59.2, U9.22 (1V2O)
unnamed: R97.1, U9.27 (ACTLED)
unnamed: R88.1, U9.10 (EXRES1)
unnamed: R96.1, U9.25 (LINKLED)
unnamed: R63.2, U9.34 (MISO)
unnamed: R65.2, U9.35 (MOSI)
unnamed: R66.2, U9.45 (PMODE0)
unnamed: R67.2, U9.44 (PMODE1)
unnamed: R68.2, U9.43 (PMODE2)
unnamed: R84.1, U9.5 (RXN)
unnamed: R85.1, U9.6 (RXP)
unnamed: R70.2, U9.33 (SCLK)
unnamed: C61.2, U9.20 (TOCAP)
unnamed: R86.1, U9.1 (TXN)
unnamed: R87.1, U9.2 (TXP)
unnamed: C55.2, R73.1, U9.30 (XI/CLKIN), Y2.1
unnamed: C56.2, R73.2, U9.31 (XO), Y2.3
unnamed: R69.2, U9.32 (~SCS)

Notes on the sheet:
Mấu chốt của Ethernet vi sai là để cho 2 dây tín hiệu có độ dài tương đối bằng nhau
Ethernet

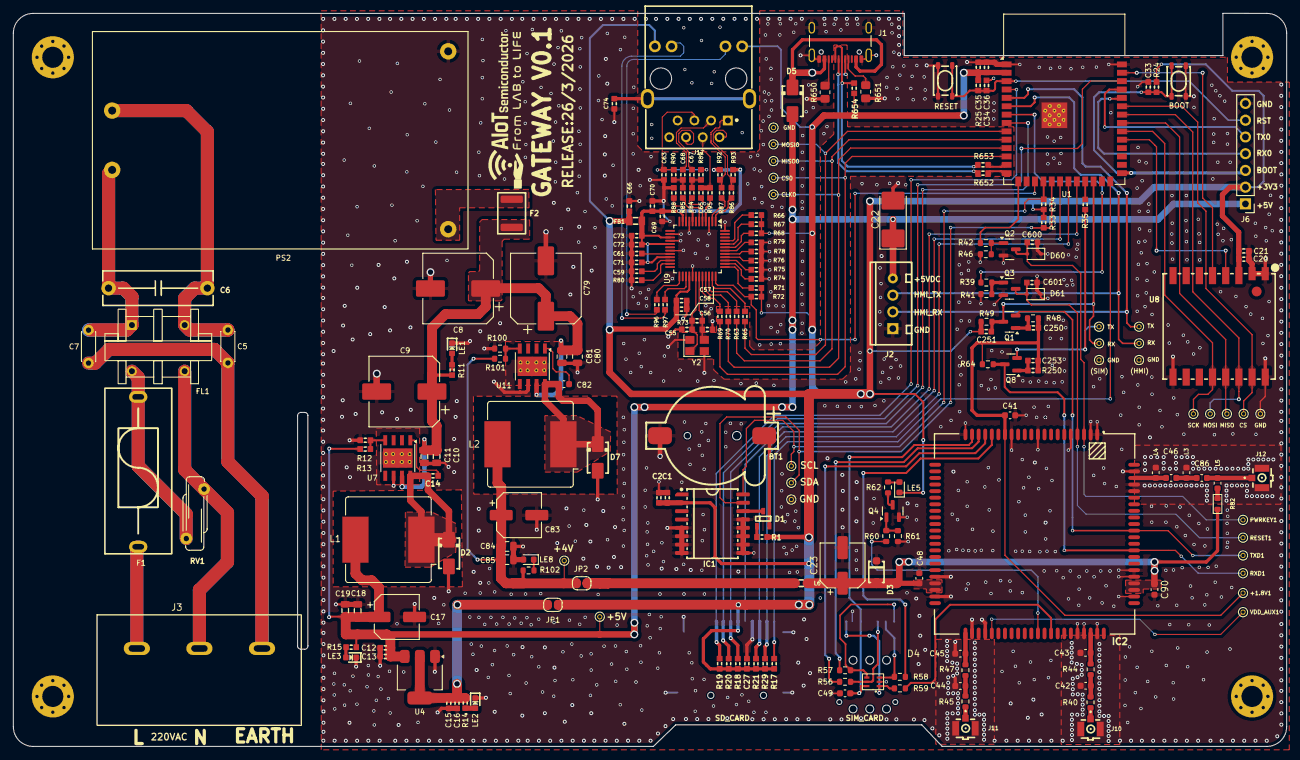
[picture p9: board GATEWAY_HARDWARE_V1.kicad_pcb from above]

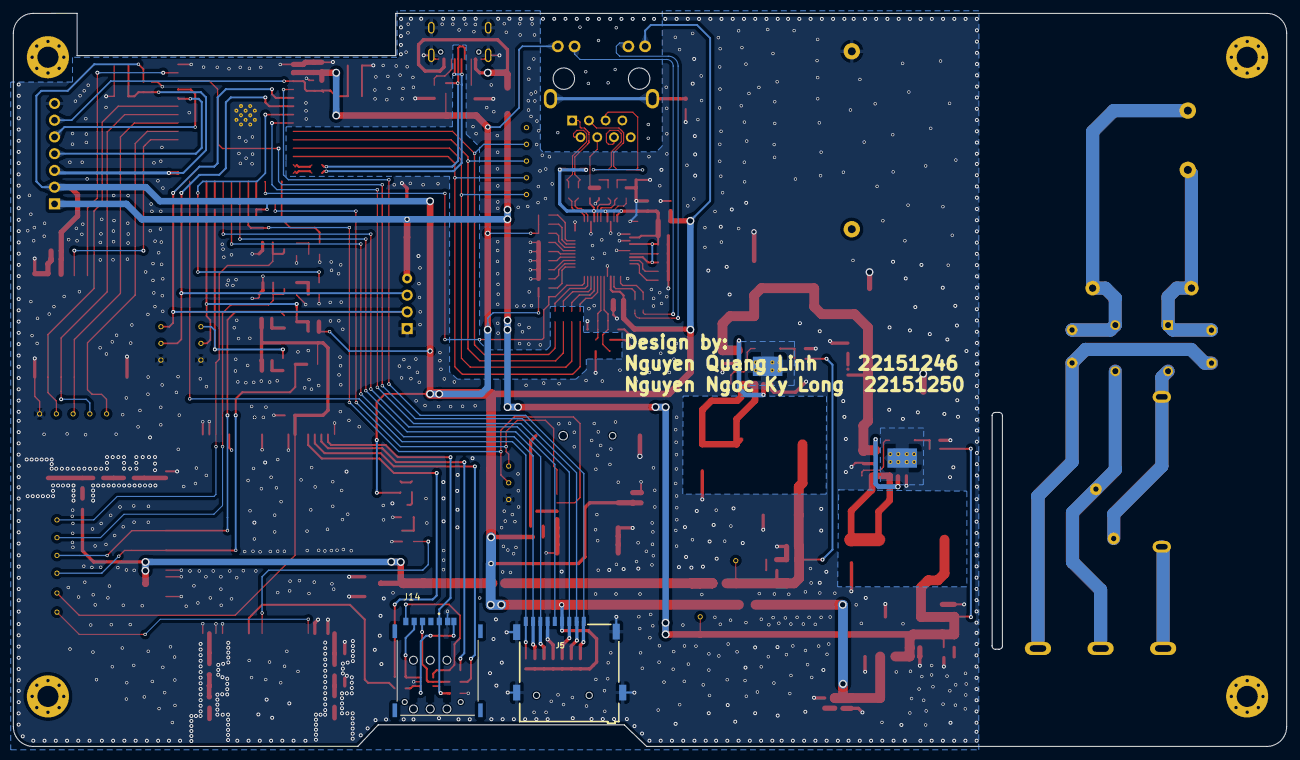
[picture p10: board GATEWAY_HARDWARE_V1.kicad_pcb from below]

Board: 2 copper layers, 193.2 x 111.3 mm, 223 parts (2 on the bottom side), 133 nets.

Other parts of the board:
GND: TestPoint; TestPoint_throughtHole_D1.0mm
GND#2, GND#3: TestPoint; TestPoint_throughtHole_D1.0mm
H1, H1#2, H1#3, H1#4: MountingHole; MountingHole_3.2mm_M3_Pad_Via

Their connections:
GND: GND#2.1, GND#3.1; also elsewhere on the board

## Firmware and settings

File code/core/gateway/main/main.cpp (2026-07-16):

/* -------------------------- LICENSE placeholder -------------------------- */
#include "esp_err.h"
#include "freertos/FreeRTOS.h"
#include "freertos/queue.h"
#include "freertos/task.h"
#include <stdint.h>
#include "esp_log.h"
#include "main.h"

static const char *TAG = "main";

StaticTask_t xLoraTaskBuffer;
StackType_t xLoraStack[LORA_STACK_SIZE];

StaticTask_t xCommonTaskBuffer;
StackType_t xCommonStack[COMMON_STACK_SIZE];

TaskHandle_t hmi_task_handle;
TaskHandle_t lora_task_handle;
TaskHandle_t common_task_handle;
TaskHandle_t network_task_handle;
// static QueueHandle_t q_common;
static QueueHandle_t q_common[TASK_ID_MAX];

typedef enum task_priority
{
    TASK_PRIORITY_DAEMON = 0,
    TASK_PRIORITY_OTHER,
    TASK_PRIORITY_COMMON,
    TASK_PRIORITY_LORA,
    TASK_PRIORITY_NETWORK,
} task_priority;

#ifdef __cplusplus
extern "C" {
#endif

void other_task(void* pvParameters) ;

void app_main(void) {

    for(uint8_t i = 0; i < TOTAL_IDX(q_common); i++) {
        q_common[i] = xQueueCreate(QUEUE_COMMON_ITEMS, sizeof(st_core_data_t));
        if(NULL == q_common[i]) {
            ESP_LOGE(TAG,"Fail to create queue: %u", i);
        }
    }
    // q_common = xQueueCreate(QUEUE_COMMON_ITEMS, sizeof(st_intertask_data_t));
    lora_task_handle = xTaskCreateStatic(
    lora_task,
    "lora_task",
    LORA_STACK_SIZE,
    NULL,
    TASK_PRIORITY_LORA,
    xLoraStack,
    &xLoraTaskBuffer
    );
    if (lora_task_handle == NULL) 
      ESP_LOGE(TAG,"Fail to create lora task");

    BaseType_t err = xTaskCreate(
    hmi_task,
    "hmi_task",
    4096,
    NULL,
    TASK_PRIORITY_COMMON,
    &hmi_task_handle
    );
    if (err != pdPASS) 
      ESP_LOGE(TAG,"Fail to create HMI task");

    common_task_handle = xTaskCreateStatic(
    common_task,
    "common_task",
    COMMON_STACK_SIZE,
    NULL,
    TASK_PRIORITY_COMMON,
    xCommonStack,
    &xCommonTaskBuffer
    );
    if (common_task_handle == NULL) 
      ESP_LOGE(TAG,"Fail to create common task");
    

    /* Highspeed CPU core to handle network task */

    
    BaseType_t ret = xTaskCreatePinnedToCore(
            network_task,           // Task function
            "network_task",         // Name for debugging
            4096,                   // Stack size in words
            NULL,                   // Task input parameter
            TASK_PRIORITY_NETWORK,  // Priority (higher number = higher priority)
            &network_task_handle,    // Task handle
            1                       // Core ID (0 or 1)
    );
    if (ret != pdPASS) 
      ESP_LOGE(TAG,"Fail to create network task");
    
    

    // xTaskCreate(other_task, "other_task", 1024 * 2, NULL, TASK_PRIORITY_OTHER, NULL);

    for(;;){
        daemon_task(NULL);
    }
}

void other_task(void* pvParameters) {

    while (1) {
      vTaskDelay(pdMS_TO_TICKS(1000));
    }
}

uint8_t get_available_queue_common()
{
    /* TODO: Change queue index base on free mutex */
    uint8_t idx = 0;
    return idx;
}
// QueueHandle_t * get_queue_common_addr() {return &q_common;}
QueueHandle_t * get_queue_common_addr() {return q_common;}
TaskHandle_t  * get_lora_task_handle() { return &lora_task_handle; }
TaskHandle_t  * get_network_handle() { return &network_task_handle; }
TaskHandle_t  * get_hmi_handle() { return &hmi_task_handle; }
TaskHandle_t  * get_common_handle() { return &common_task_handle; }

#ifdef __cplusplus
}
#endif

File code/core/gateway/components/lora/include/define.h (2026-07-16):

#ifndef DEFINE_H
#define DEFINE_H

#define HOST_ID           SPI2_HOST

// #define CS_GPIO    CONFIG_CS_GPIO  
// #define MOSI_GPIO  CONFIG_MOSI_GPIO
// #define MISO_GPIO  CONFIG_MISO_GPIO
// #define SCK_GPIO   CONFIG_SCK_GPIO 
// #define RST_GPIO   CONFIG_RST_GPIO 

#define CS_GPIO   42
#define MOSI_GPIO 41
#define MISO_GPIO 40
#define SCK_GPIO  39
#define RST_GPIO  38

#endif

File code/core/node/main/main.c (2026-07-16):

/* -------------------------- LICENSE placeholder -------------------------- */

#include <inttypes.h>
#include <stdio.h>
#include <string.h>

#include "esp_log.h"
#include "main.h"


StaticTask_t xLoraTaskBuffer;
StackType_t xLoraStack[LORA_STACK_SIZE];

StaticTask_t xModbusTaskBuffer;
StackType_t xModbusStack[MODBUS_STACK_SIZE];
TaskHandle_t modbus_task_handle;
TaskHandle_t lora_task_handle;
TaskHandle_t network_task_handle;

// static QueueHandle_t q_common[5];
static QueueHandle_t q_common;

static const char *TAG = "main";

void app_main() {
    // for(uint8_t i = 0; i < sizeof(q_common)/sizeof(QueueHandle_t); i++) {
    //     q_common[i] = xQueueCreate(QUEUE_COMMON_SIZE, sizeof(st_modbus_intertask_t));
    //     if(NULL == q_common[i]) {
    //         ESP_LOGE(TAG,"Fail to create queue: %u", i);
    //     }
    // }
    q_common = xQueueCreate(QUEUE_COMMON_ITEMS, sizeof(st_intertask_data_t));

    lora_task_handle = xTaskCreateStatic(
    lora_task,
    "lora_task",
    LORA_STACK_SIZE,
    NULL,
    2,
    xLoraStack,
    &xLoraTaskBuffer
    );
    if (lora_task_handle == NULL) 
      ESP_LOGE(TAG,"Fail to create lora task");

    modbus_task_handle = xTaskCreateStatic(
    modbus_task,
    "modbus_task",
    MODBUS_STACK_SIZE,
    NULL,
    1,
    xModbusStack,
    &xModbusTaskBuffer
    );
    if (modbus_task_handle == NULL) 
      ESP_LOGE(TAG,"Fail to create modbus task");

    for(;;){
        vTaskDelay(pdMS_TO_TICKS(1000));
    }

}

uint8_t get_available_queue_common()
{
    /* TODO: Change queue index base on free mutex */
    uint8_t idx = 0;
    return idx;
}
// QueueHandle_t * get_queue_common_addr() {return q_common;}
QueueHandle_t * get_queue_common_addr() {return &q_common;}
TaskHandle_t  * get_modbus_task_handle() { return &modbus_task_handle; }
TaskHandle_t  * get_lora_task_handle() { return &lora_task_handle; }
TaskHandle_t  * get_network_handle() { return &network_task_handle; }

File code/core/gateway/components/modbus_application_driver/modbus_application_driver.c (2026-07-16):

/* -------------------------- LICENSE placeholder -------------------------- */
#include <stdbool.h>
#include <stdint.h>
#include <stdio.h>
#include <string.h>
#include <stdlib.h>
#include "freertos/FreeRTOS.h"
#include "freertos/task.h"
#include "freertos/queue.h"
#include "driver/uart.h"
#include "driver/gpio.h"
#include "esp_log.h"
#include "modbus_application_driver.h"
#include "modbus_payload_handle.h"

static const char TAG[] = "modbus_driver";
static QueueHandle_t q_uart_event;
#define UART_EVEN_SIZE 10


// --- BẢNG TRA CRC16 MODBUS (256 phần tử) ---
static const uint16_t crc_table[] = {
    0x0000, 0xC0C1, 0xC181, 0x0140, 0xC301, 0x03C0, 0x0280, 0xC241,
    0xC601, 0x06C0, 0x0780, 0xC741, 0x0500, 0xC5C1, 0xC481, 0x0440,
    0xCC01, 0x0CC0, 0x0D80, 0xCD41, 0x0F00, 0xCFC1, 0xCE81, 0x0E40,
    0x0A00, 0xCAC1, 0xCB81, 0x0B40, 0xC901, 0x09C0, 0x0880, 0xC841,
    0xD801, 0x18C0, 0x1980, 0xD941, 0x1B00, 0xDBC1, 0xDA81, 0x1A40,
    0x1E00, 0xDEC1, 0xDF81, 0x1F40, 0xDD01, 0x1DC0, 0x1C80, 0xDC41,
    0x1400, 0xD4C1, 0xD581, 0x1540, 0xD701, 0x17C0, 0x1680, 0xD641,
    0xD201, 0x12C0, 0x1380, 0xD341, 0x1100, 0xD1C1, 0xD081, 0x1040,
    0xF001, 0x30C0, 0x3180, 0xF141, 0x3300, 0xF3C1, 0xF281, 0x3240,
    0x3600, 0xF6C1, 0xF781, 0x3740, 0xF501, 0x35C0, 0x3480, 0xF441,
    0x3C00, 0xFCC1, 0xFD81, 0x3D40, 0xFF01, 0x3FC0, 0x3E80, 0xFE41,
    0xFA01, 0x3AC0, 0x3B80, 0xFB41, 0x3900, 0xF9C1, 0xF881, 0x3840,
    0x2800, 0xE8C1, 0xE981, 0x2940, 0xEB01, 0x2BC0, 0x2A80, 0xEA41,
    0xEE01, 0x2EC0, 0x2F80, 0xEF41, 0x2D00, 0xEDC1, 0xEC81, 0x2C40,
    0xE401, 0x24C0, 0x2580, 0xE541, 0x2700, 0xE7C1, 0xE681, 0x2640,
    0x2200, 0xE2C1, 0xE381, 0x2340, 0xE101, 0x21C0, 0x2080, 0xE041,
    0xA001, 0x60C0, 0x6180, 0xA141, 0x6300, 0xA3C1, 0xA281, 0x6240,
    0x6600, 0xA6C1, 0xA781, 0x6740, 0xA501, 0x65C0, 0x6480, 0xA441,
    0x6C00, 0xACC1, 0xAD81, 0x6D40, 0xAF01, 0x6FC0, 0x6E80, 0xAE41,
    0xAA01, 0x6AC0, 0x6B80, 0xAB41, 0x6900, 0xA9C1, 0xA881, 0x6840,
    0x7800, 0xB8C1, 0xB981, 0x7940, 0xBB01, 0x7BC0, 0x7A80, 0xBA41,
    0xBE01, 0x7EC0, 0x7F80, 0xBF41, 0x7D00, 0xBDC1, 0xBC81, 0x7C40,
    0xB401, 0x74C0, 0x7580, 0xB541, 0x7700, 0xB7C1, 0xB681, 0x7640,
    0x7200, 0xB2C1, 0xB381, 0x7340, 0xB101, 0x71C0, 0x7080, 0xB041,
    0x5000, 0x90C1, 0x9181, 0x5140, 0x9301, 0x53C0, 0x5280, 0x9241,
    0x9601, 0x56C0, 0x5780, 0x9741, 0x5500, 0x95C1, 0x9481, 0x5440,
    0x9C01, 0x5CC0, 0x5D80, 0x9D41, 0x5F00, 0x9FC1, 0x9E81, 0x5E40,
    0x5A00, 0x9AC1, 0x9B81, 0x5B40, 0x9901, 0x59C0, 0x5880, 0x9841,
    0x8801, 0x48C0, 0x4980, 0x8941, 0x4B00, 0x8BC1, 0x8A81, 0x4A40,
    0x4E00, 0x8EC1, 0x8F81, 0x4F40, 0x8D01, 0x4DC0, 0x4C80, 0x8C41,
    0x4400, 0x84C1, 0x8581, 0x4540, 0x8701, 0x47C0, 0x4680, 0x8641,
    0x8201, 0x42C0, 0x4380, 0x8341, 0x4100, 0x81C1, 0x8081, 0x4040
};

// Hàm tính nhanh bằng bảng tra cứu
// --- HÀM TÍNH TOÁN CRC16 MODBUS SỬ DỤNG BẢNG TRA ---
uint16_t crc16_modbus(const uint8_t *data, uint16_t len) {
    uint16_t crc = 0xFFFF;
    
    for (uint16_t i = 0; i < len; i++) {
        uint8_t byte = data[i];
        crc = (crc >> 8) ^ crc_table[(crc ^ byte) & 0xFF];
    }
    
    return crc;
}

esp_err_t modbus_send(e_modbus_function_t modbus_func, uint8_t slave_id, uint16_t reg_addr, uint16_t payload) {
    if(MB_FUNC_R_COIL > modbus_func && MB_FUNC_W_HOLDING < modbus_func)
        return ESP_ERR_INVALID_ARG;
    uint8_t frame[8];
    frame[0] = slave_id;
    frame[1] = modbus_func;
    frame[2] = (reg_addr >> 8) & 0xFF;
    frame[3] = reg_addr & 0xFF;
    frame[4] = (payload >> 8) & 0xFF;
    frame[5] = payload & 0xFF;
    uint16_t crc = crc16_modbus(frame, 6);
    frame[6] = crc & 0xFF;          // Byte thấp CRC
    frame[7] = (crc >> 8) & 0xFF;   // Byte cao CRC
    /* Request or write modbus message */
    m_modbus_payload_handle((void*)frame, 1);
    uart_write_bytes(UART_PORT, (const char*) frame, 8);
    return ESP_OK;
}

esp_err_t modbus_uart_event_handle() 
{
    uart_event_t event;
    if (xQueueReceive(q_uart_event, (void*)&event, pdMS_TO_TICKS(1000))) {
        uint8_t* dtmp = (uint8_t*)malloc(128);
        if(!dtmp) {
            ESP_LOGE(TAG, "Fail to allocate buffer");
            return ESP_ERR_NO_MEM;
        }
        bzero(dtmp, MODBUS_UART_BUF_SIZE);
        switch (event.type) {
            case UART_DATA:
                // Đọc dữ liệu từ Ring Buffer
                int len = uart_read_bytes(UART_PORT, dtmp, event.size, pdMS_TO_TICKS(10));
                if (len >= 5) {
                    /* If return value is not 0, CRC mismatch happen */
                    if (crc16_modbus(dtmp, len)){
                        ESP_LOGE(TAG, "Sai mã CRC!");
                        return ESP_ERR_INVALID_CRC;
                    }
                    /* Response modbus message */
                    m_modbus_payload_handle(dtmp, 0);
                }
                break;

            case UART_FIFO_OVF:
                ESP_LOGW("INT", "Tràn bộ đệm FIFO!");
                uart_flush_input(UART_PORT);
                xQueueReset(q_uart_event);
                break;

            case UART_PARITY_ERR:
                ESP_LOGE(TAG, "Lỗi Parity - Kiểm tra nhiễu!");
                break;
            case UART_BREAK:
                break;

            default:
                ESP_LOGE(TAG, "Unspecified event");
                break;
        }
        free(dtmp);
        dtmp = NULL;

    }
    return ESP_OK;
}

void modbus_init() {
    // 1. Cấu hình UART
    uart_config_t uart_config = {
        .baud_rate = BAUD_RATE,
        .data_bits = UART_DATA_8_BITS,
        .parity = UART_PARITY_DISABLE,
        .stop_bits = UART_STOP_BITS_1,
        .flow_ctrl = UART_HW_FLOWCTRL_DISABLE,
        .source_clk = UART_SCLK_DEFAULT,
    };

    ESP_ERROR_CHECK(uart_driver_install(UART_PORT, 255, 255, UART_EVEN_SIZE, &q_uart_event, 0));
    ESP_ERROR_CHECK(uart_param_config(UART_PORT, &uart_config));
    
    // 2. Gán chân và chế độ RS485
    ESP_ERROR_CHECK(uart_set_pin(UART_PORT, TXD_PIN, RXD_PIN, RTS_DE_PIN, CTS_PIN));
    ESP_ERROR_CHECK(uart_set_mode(UART_PORT, UART_MODE_RS485_HALF_DUPLEX));

    // 3. Cấu hình chân RE (IO15)
    gpio_reset_pin(RE_PIN);
    gpio_set_direction(RE_PIN, GPIO_MODE_OUTPUT);
    gpio_set_level(RE_PIN, 0); // RE=0 để luôn cho phép module nhận dữ liệu từ biến tần

    // 4. Chế độ RS485 Half Duplex (Tự động kéo DE lên 1 khi gửi)
    ESP_ERROR_CHECK(uart_set_mode(UART_PORT, UART_MODE_RS485_HALF_DUPLEX));

    // 5. Bật nguồn module RS485 
    gpio_reset_pin(RS485_EN_PIN);
    gpio_set_direction(RS485_EN_PIN, GPIO_MODE_OUTPUT);
    gpio_set_level(RS485_EN_PIN, 1);
}

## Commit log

2026-04-20 Merge nhánh Hardware vào nhánh dev (#1)
    * feat: Add hardware folder
    * refactor: Remove old schematic, add new PCB layout
    * Update Gateway PCB Layout 22/3/2026 (After review)
    * Update PCB Layout for Gateway, 23/3/2026
    * Update PCB Layout for Gateway (24/3/2026)
    * Update PCB Layout Gateway (24/3/2026)
    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
    [ESP32-S3.kicad_sch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]
2026-04-20 Scrum 34 mqtt for ethernet w5500 (#3)
    * SCRUM-34 Migrate unit test code from scrum 28
    * SCRUM-34 refactor: cleanup SPI test code
    * SCRUM-34 feat: ping google.com succesfully
    * SCRUM-34 feat: embed mosquitto broker cert to image binary, test successfully with SSL/TLS
    [ethernet_w5500.c, main.c]
2026-04-20 Scrum 28 write ethernet w5500 unit test (#5)
    * SCRUM-28 Add pseudo code
    * feat: output SPI pins success, use logic analyzer to capture
    * Fix: remove magic number
    * test: Burst transfer over 1500 byte to MOSI
    * feat: Initialize W5500 with ethernet_init dependency successfully
    * feat: Missing esp_netif_init() to get IP
    * SCRUM-28 feat: Initialize Ethernet successfully, get IP address from router
    ---------
    [ethernet_w5500.c, main.c]
2026-04-20 refactor(hardware): move .gitignore and ESP32S3 pin table to hardware folder, rename gateway_hardware_schematic
    [ESP32-S3.kicad_sch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]
2026-04-20 Scrum 41 unit test lora node gd20 inverter esp32 (#7)
    * Initial commit
    * Add LoRa library submodule
    * Fetch: New library ESP-MODBUS as submodule
    * SCRUM-41 Create pseudo project structure
    * SCRUM-41 Lora node tests GD20 Inverter
    * SCRUM-41 Lora node tests GD20 Inverter
    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
2026-04-23 feat(esp32s3): change spi pin to map gateway board
2026-04-27 Scrum 59 connect esp32 to vps mqtt broker with tls ssl (#15)
    * SCRUM-59 feat(wifi): Successfully get IP address
    * SCRUM-59 feat(kconfig): Use Kconfig for SSID and password
    * experiment network components
    * SCRUM-59 refactor(components): network component includes wifi_app and mqtts"
    Restructure components
    network component contains wifi_app and mqtts subcomponents
    Use one network_event_group for WiFi, Ethernet, MQTT, etc...
    * SCRUM-59 feat(mqtt): Successfully connected to broker without TLS/SSL
    * SCRUM-59 feat(tls/ssl): Successfully connect with MQTT TLS/SSL broker
    * SCRUM-59 refactor: remove wifi and ethernet folder
    * SCRUM-59 feat(eth): add Ethernet W5500 with Kconfig to select net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
    [eth_w5500_app.c, main.c]
2026-04-27 feat(rename): rename unit test mqtts with cloud vps broker
    [eth_w5500_app.c, main.c]
2026-04-28 Upload code for test rtc DS3231 (#17)
    * Upload unit_test_rtc_ds3231
    [ESP32-S3.kicad_sch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]
2026-04-28 Restore hardware folder
    [ESP32-S3.kicad_sch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]
2026-04-29 Merge Scrum 86 cicd for gd20 modbus on gateway board (#18)
    * feat(pincfg,gateway): Use Gateway HMI UART pin to control inverter GD20
    * fix(name): rename unit test gd20 inverter for lora node and gateway
    * SCRUM-86 feat(cicd): Prepare workflow and python script
    * SCRUM-86 ci(pyscript): Update log capture regex
    * SCRUM-86 fix(name): fix workflows
    * SCRUM-86 fix(components): missing CMakeLists and source file
    * SCRUM-86 feat(main.c): remove FreeRTOS task to prevent inverter loop test
    * SCRUM-86 ci(debug): fix log_capturer path and debug requirements
    * Rename and update unit test workflow jobs
    * SCRUM-86 fix(main.c): Restore task loop in main
    * SCRUM-86 fix(script): Fix python script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
    [gd20_inverter.h, main.c, modbus_application_driver.c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]
2026-04-29 Scrum 43 write python script to communicate via usb cdc (#16)
    * push
    * Change ESP-IDF activation script path
    Updated script paths for loading ESP-IDF to new location.
    * Change to bash shell
    * change source to dot
    * SCRUM-43 fix(build): remove build folder
    * SCRUM-43 ci(workflow): build flash monitor in single script
    * SCRUM-43 ci(target): Add set-target esp32-s3 option
    * Modify build command in node.js.yml
    Updated build command to remove 'monitor' option.
    * SCRUM-43 refactor(modular): Migrate source code to tools/usb_cdc folder
    * SCRUM-43 ci(pip,requirement): Add pip requirements.txt and make sure pip packages are available before running CI script
    * SCRUM-43 fix(esp32s3): update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
2026-04-30 Merge request Scrum 87 design GitHub workflow Upgrade workflow (#21)
    * SCRUM-87 ci(workflows): Create workflows for specific type
    * SCRUM-87 fix: Syntax in coordinator_workflow.yml
    * SCRUM-87 fix experiment_debug_workflow.yml
    * SCRUM-87 fix syntax main workflow
    * SCRUM-87 fix choice type in unit_test_workflow
    * Update unit_test_workflow.yml
    * Update stub.yml
    Added inputs for workflow selection and unit test project in the coordinator workflow.
    * Fix indentation and formatting in workflow file
    * Remove on.push and add new message
    * Remove on.push in coordinator
    * SCRUM-87 test, ci(shell): Passing inputs to bash shell to test variable
    * SCRUM-87 ci(rename): Rename unit test project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
    [ethernet_w5500.c, main.c]
2026-05-01 Merge request unit-test_lora_gateway source code (#10)
    * feat(lora) : Receive data from lora node
    * refactor (lora node):
    * refactor (lora gateway): test receiver from lora node
    * docs: change Readme.md
    * docs: fix Readme.md
    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
    [define.h, lora.c]
2026-05-01 Update ci and configure job mqtts vps broker (#22)
    * ci(env): Replace with vars.HOST_RUNNER_PATH in unit_test_workflow
    * ci(coordinator): change unit test to mqtts_vps_broker to reduce test overhead
    * fix shell syntax
    * ci(log): Add LOG START and LOG END to capture log
    * ci(log): Increase log time
    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
    [main.c]
2026-05-01 fix(wifi): change esp32s3 cfg, remove .gitmodule and update .gititnore
2026-05-01 Scrum 56 improve baremetal modbus library trial uart interrupt (#20)
    * SCRUM-41 feat(esp32c3): Read GD20 ID code successfully
    * SCRUM-60 refactor: move modbus driver to components folder
    * Config for ESP32S3
    * feat(modbus): update communication functions and inverter data processing
    - Cập nhật hàm modbud_read_single_register để hỗ trợ đọc thanh ghi đơn.
    - Thêm/cập nhật modbud_write_register phục vụ việc ghi dữ liệu xuống thiết bị.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
2026-05-03 Merge request unit-test_lora_node source code (#9)
    * feat(lora) : Sent data to lora gateway
    * refactor (lora node): test sent to lora gateway
    * docs(Readme.md)
    * chora: change path
    * chora: change path
    * fix(path): remove code/code/unit-test path
    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
    [define.h, lora.c]
2026-05-09 MR: Unit test MQTTS User Authenticate (#25)
    * feat(cert): Reuse unit-test_mqtts_vps_broker, add kolabori.pem certificate, test TLS/SSL successfully
    * SCRUM-103 ci(unit-test): add unit-test_mqtts_user_authenticate to github workflow
    * SCRUM-103 fix(cert): add certificates folder to git cache
    * feat(kconfig): add MQTT username and password to Kconfig, authenticate successfully
    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
    [eth_w5500_app.c, main.c]
2026-05-09 SCRUM-97 refactor(lora,define): change Lora SPI name in lora.c library
2026-05-09 SCRUM-97 feat(gateway,task): build static Lora and network pin core 1 pass, not test yet
2026-05-09 SCRUM-97 fix(stack_ovfl):Increase stack lora task to 2048
    [main.c]
2026-05-11 SCRUM-97 fix(modbus,crc): restore crc16_table
    [modbus_application_driver.c]
2026-05-14 Merge Lora protocol to Create project structure (#26)
    * SCRUM-100 build(lora_protocol): add lora_protocol in middleware folder and build successfully
    * SCRUM-100 build(protocol): build success on node, not test
    * SCRUM-100 feat: add MIN macro define
    * SCRUM-100 build(gateway): Add lora_protocol
    * SCRUM-100 fix(callback): fix callback lora_protocol and test SHT20 packet
    * SCRUM-100 feat(gateway): add test_receive in gateway
    * SCRUM-100 fix(callback): revert return value to void for lorar_protocol callback function
    * SCRUM-100 feat(protocol): fix parse function and use calloc to copy payload to callback
    * SCRUM-100 fix(protocol): successfully send SHT20 data
    ---------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
    [lora_task.c]
2026-05-16 SCRUM-97 fix(esp_log): remove ESP log in lora_protocol, add new error code and update error check flow code
    [lora_task.c]
2026-05-27 feat(modbus_driver): refactor modbus component
    Add callback tx, rx and error
    Change uart_event_task to uart_event_handler
    Simplify modbus_send and CRC check
    Change modbus function read write to macro MODBUS_FUNC_W and MODBUS_FUNC_R
    [modbus_application_driver.c, modbus_application_driver.h]
2026-05-27 feat: add modbus driver callback handler and move node_device_typedef to modbus middleware
2026-05-29 feat(enum modbus function): shorten enum MODBUS_ to MB_
    [modbus_application_driver.c, modbus_application_driver.h]
2026-05-29 feat(uart_event_handler): free memory of dtmp and set pointer to NULL
2026-05-30 SCRUM-113 feat(modbus payload): Add modbus descriptor and device info
2026-05-30 SCRUM-113 fix(modbus driver): fix runtime bugs and update lora node RS485 pin
    [modbus_application_driver.c, modbus_application_driver.h]
2026-05-31 SCRUM-113 feat(error callback): add error callback in modbus_task
    [lora_task.c]
2026-06-01 SCRUM-113 fix: modbus function pointer callback
    [modbus_application_driver.c, modbus_application_driver.h]
2026-06-05 Merge SCRUM-113 modbus payload handle middleware (#29)
    * note draf
    * write draft
    * SCRUM-113 feat(GD_20): test sent modbud_task
    * SCRUM-113 feat(modbus): add draft middleware modbus
    * feat(modbus_driver): refactor modbus component
    * feat: add modbus driver callback handler and move node_device_typedef to modbus middleware
    * feat(main): Add queue common and get task handler function
    * feat(enum modbus function): shorten enum MODBUS_ to MB_
    * feat(uart_event_handler): free memory of dtmp and set pointe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
    [gd20_inverter.h, lora_task.c, main.c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]
2026-06-06 SCRUM-115 feat(intertask): upgrade intertask logic
    - Add union intertask_noti to notify error code, queue index via
    xTaskNotify value
    - Change pointer intertask_data.payload member to uint8_t buffer named coredata to prevent copy pointer to queue (lora_protocol parse completed allocated memory may free data before intertask handle the payload)
    - Change Lora node address to 2
    - Add notify_intertask, seperate logic task notify to a function
    - Change name send_to_intertask to notify_intertask
    - Add handle u_intertask_noti_t in handle_intertask_request
    - Add TASK_ID_SDCARD
    [lora_task.c]
2026-06-07 Scrum 90 design and communication between dwin and esp32 (#27)
    * SCRUM-90 feat(DWIN): unit test communication between ESP32S3 and DWIN display using Arduino IDE
    * SCRUM_90:FEAT(Design_UI)
    * SCRUM 90: Update Unit code for DWIN
    * SCRUM-90 feat(hmi): rename unit-test_hmi_dwin and build successfully
    * SCRUM-90 feat(hmi): Porting HMI Arduino code to ESP-IDF, build success, not test
    * SCRUM_90:Update ESP_IDF code DWIN - ESP32
    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
2026-06-08 SCRUM-115 fix(modbus function): support more modbus function and check type in middleware
    [modbus_application_driver.c, modbus_application_driver.h]
2026-06-09 SCRUM-115 feat(gw mb driver): update modbus driver from node
2026-06-09 SCRUM-115 feat(lora protocol): use src and dest addr
    - Simplify frame parse logic and add st_lora_protocol_header_t to parse callback
    - Change error code from LORA_PROTOCOL_ERR_OK to LORA_PROTOCOL_OK
    - Update st_lora_protocol_header_t to support dest and src address
2026-06-09 SCRUM-115 feat(node): Add intertask logic code
    - Update lora_task logic to support new update lora_protocol middleware
    - Handle new error code of modbus middleware MB_PAYLOAD_ERR_MODBUS_TYPE to check supported modbus function
    [lora_task.c]
2026-06-09 SCRUM-115 feat, fix: successfully receive modbus data from node lora to gateway
    [lora_task.c, main.c]
2026-06-10 SCRUM-102 feat(hmi driver): update hmi_event_cb
2026-06-12 SCRUM-115 fix(modbus_driver buf size): change to MODBUS_UART_BUF_SIZE to avoid conflicting with redefined DWIN BUF_SIZE
    [modbus_application_driver.c, modbus_application_driver.h]
2026-06-12 SCRUM-102 feat(hmi): Update HMI button handle, create helper func intertask modbus
2026-06-13 SCRUM-102 feat(hmi): update HMI driver logic code
    Add HMI parse callback handle
    Add struct st_hmi_frame_t
2026-06-14 SCRUM-115,SCRUM-102 feat: Successfully control GD20 inverter via HMI DWIN
    Fix logic of lora_protocol
    Reduce core data size to 20
    Reduce lora buffer size
    Add raw logic of send text to HMI
    [dwin_app_driver.cpp, lora_task.c]
2026-07-16 SCRUM-101 feat(gw): successfully connected to MQTT broker
    [network_task.c]
2026-07-16 SCRUM-101 feat(mqtt): Successfully sub and pub to broker
    [network_task.c]
2026-07-16 SCRUM-101 feat(intertask): Add intertask handler to network_task, change MQTT log on error
    [network_task.c]
2026-07-16 SCRUM-101 fix(modbus function): Correct Write holding function code
    [network_task.c]
2026-07-16 SCRUM-101 fix(node): revert node source code after rebase from scrum_115
    [lora_task.c, main.c]
2026-07-16 SCRUM-101 fix(core ID): arrange core data ID and change to unit8_t
    [lora_task.c, main.cpp, network_task.c]
2026-07-16 SCRUM-101 feat(gateway): Successfully request data, control from HMI and network to GD20
    Add GD20_REG_STATUS request in common_task and handle in network_task
    Change lora address to 20
    Reduce timeout intertask of lora_task
    Remove g_topic_gd20_data multiply by 100 in network_intertask_core_function
    Add some debug log in lora_task to debug send and receive buffer
    Fix logic of request_idx in common_task
    [lora_task.c, network_task.c]
2026-07-16 SCRUM-101 feat(hmi): filter vp 0x4f4b out of the log
2026-07-16 SCRUM-101 fix(reply task handle id, lora): fix logic check reply task handle HMI and NETWORK, send multiple request control gd20
    [lora_task.c, network_task.c]
2026-07-16 SCRUM-101 fix(default switch, node): print coredata.cdataid in handle_intertask_request
2026-07-16 SCRUM-101 feat(sdkconfig,ethernet): update W5500 SPI pins in menuconfig
